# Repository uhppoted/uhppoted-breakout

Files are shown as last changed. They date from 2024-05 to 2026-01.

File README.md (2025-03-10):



# uhppoted-breakout

Breakout board for the UHPPOTE TCP/IP Wiegand 26 access controllers. 

The breakout board substitutes the removable CPU board with a hackable board that:
- Exposes the interface connector pins as a pair of standard 2.54mm (0.1") headers
- Serialises card swipes and I/O events out to an SPI interface
- Has mounting holes for an external CPU to do the heavy lifting (e.g. _RaspberryPi_ _Zero2W_)
- Includes an onboard RTC

## Raison d'être

Mostly curiosity? But .. it also opens up the possibility of:
- IPv6
- TLS
- UDP multicast
- onboard WiFi
- interfacing with off brand readers and keypads
- custom access control requirements

## Roadmap

### Rev.0

**IN DEVELOPMENT**

Initial proof of concept, designed to be relatively easy to hand solder and debug:
- All the components are on the front (top) of the PCB
- It uses the ever-so-cute _WaveShare_ _RP2040-Tiny_ module
- Through-hole components where convenient

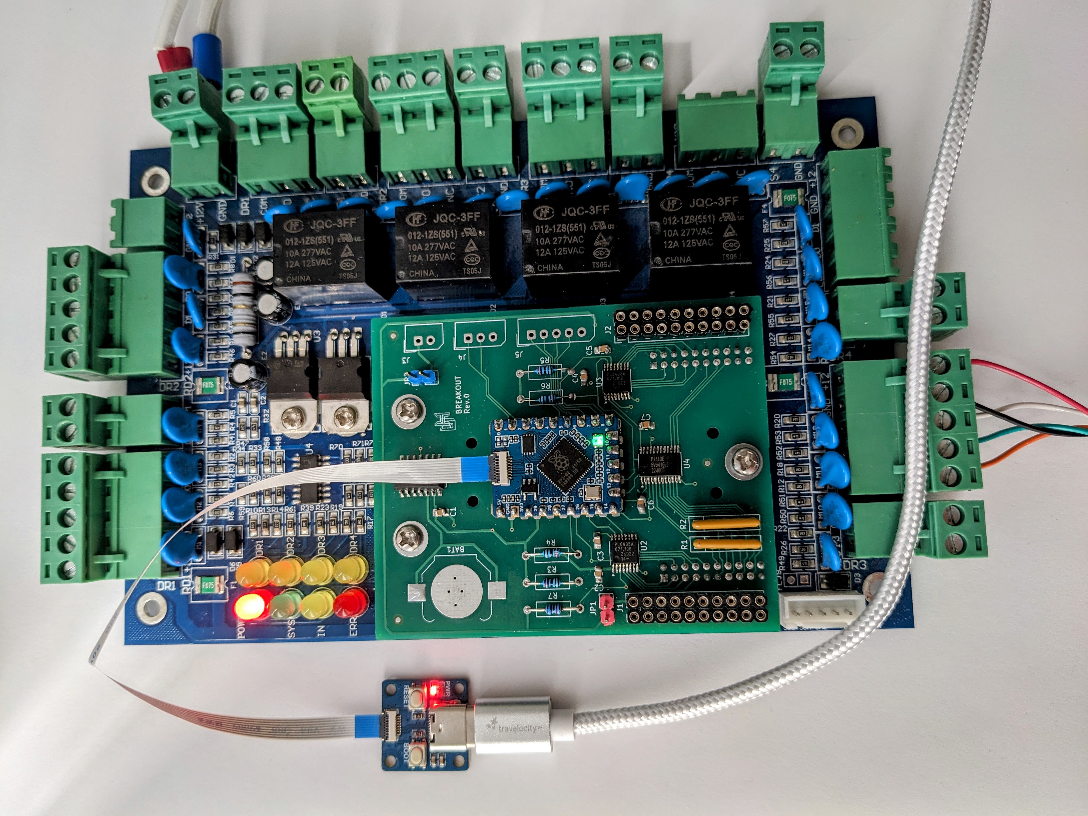
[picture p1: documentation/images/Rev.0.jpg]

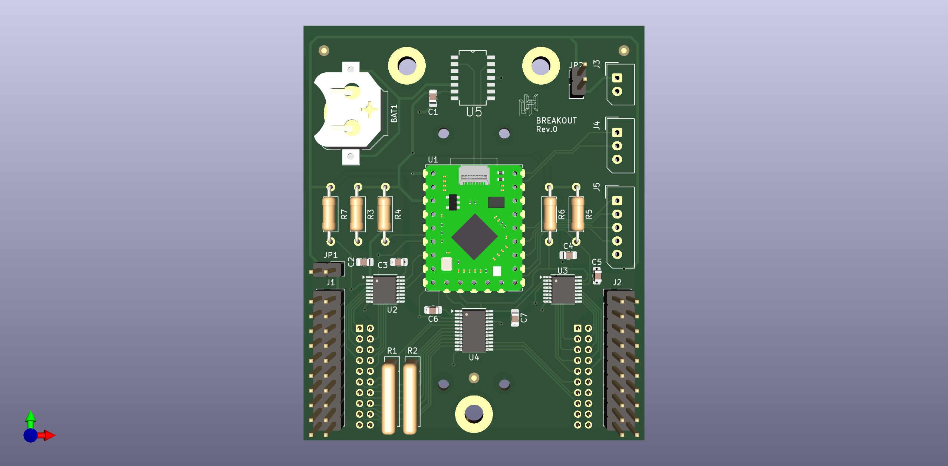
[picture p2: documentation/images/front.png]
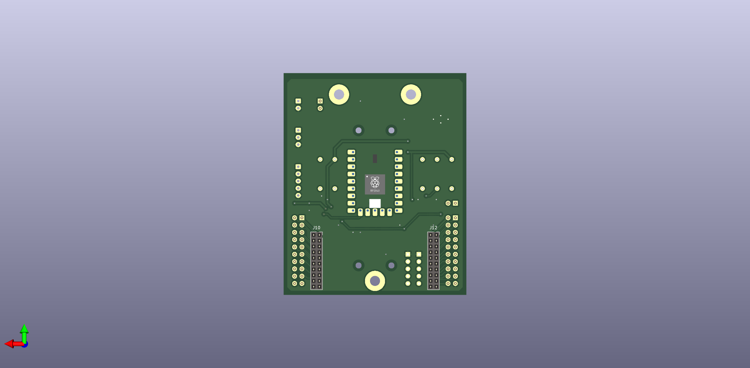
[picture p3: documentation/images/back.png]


#### Errata
1. Requires Schottky barrier diode and resistor on RX8900SA backup battery.
2. Add-on mounting holes are for RaspberryPi Pico.

## Notes

### Footprints
1. The silkscreen footprint for J10 and J12 on the CPU board of the controller is either mirrored or
   using the footprint for a pin header (presumably because the pin and socket headers were swapped for
   easier assembly and the silkscreen was never updated).

2. The silkscreen footprint for J10 and J11 on the base board of the controller is either mirrored or
   using the footprint for a pin socket (presumably because the pin and socket headers were swapped for
   easier assembly and the silkscreen was never updated).

3. The breakout board uses the correct footprints for the J10 and J12 socket headers that connect the
   board to the base board.

## License

Hardware is licensed under the CERN-OHL-S-2.0-S license, software is licensed under the MIT license.

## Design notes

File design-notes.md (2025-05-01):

# DESIGN NOTES

## UT0311L04

### Power Consumption

| Configuration | Measured | Power  |
|---|---|---|
| Base + CPU | 155mA  @ 12.21V | 1.9W |
| Base | 16.5mA @ 12.23V | 0.2W |
| Breakout Rev 0.0 | 25.4mA @ 5.10V  | 0.13W  |

### Startup

| RELAY | N/O | N/C | LED |
|---|---|---|-----|
| 1 | OPEN | CLOSED | +5V |
| 2 | OPEN | CLOSED | +5V |
| 3 | OPEN | CLOSED | +5V |
| 4 | OPEN | CLOSED | +5V |

### Relays
1. +5V/(1k || 10.470k) = 4.5mA
2. ULN2003A = 5V * 10k(10k + 470) = 4.77V

### Reader LEDs
1. +5V/470 = 10.6mA
2. Assumed to be high impendance signal (not driving LED directly)

### SYS, ERR and IN LEDs
1. (+5V - D5 - D6)/1k = (+5V - 0.6 - 0.6)/1k = 3.8mA

### References
1. https://www.cnx-software.com/2021/12/09/raspberry-pi-zero-2-w-power-consumption
2. https://raspi.tv/2017/how-much-power-does-pi-zero-w-use

## PCAL6408APW

### Input Schmmitt trigger
- Vᴅᴅ   = 5V
- Vʟᴏᴡ  = 0.3Vᴅᴅ (1.5V)
- Vʜɪɢʜ = 0.7Vᴅᴅ (3.5V)
- Vʜ    = 3.5V - 1.5V = 2V

## SSMP
1. Does not handle bignums.

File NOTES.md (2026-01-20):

# NOTES

1.  https://www.digikey.ca/en/articles/use-tight-pitch-board-to-board-connectors
2.  https://github.com/vlang/vinix
3.  BSS1338 or 2N7002 https://hackaday.com/2023/05/02/fet-fun-endeavors-together
4.  https://hackaday.com/2016/12/05/taking-it-to-another-level-making-3-3v-and-5v-logic-communicate-with-level-shifters/
5.  https://www.cnx-software.com/2023/10/09/waveshare-rp2040-pizero-raspberry-pi-rp2040-board-raspberry-pi-zero-form-factor/
6.  https://hackaday.com/2024/03/18/rnode-a-portable-unrestricted-digital-radio
7.  https://www.diodes.com/design/support/technical-articles/simplify-your-embedded-designs-using-ic-io-expanders
8.  https://www.diodes.com/assets/Datasheets/PI4IOE5V6416.pdf
9.  https://www.diodes.com/assets/Datasheets/PI4IOE5V6524.pdf
10. SMD adapters
    - https://www.icbreakout.com/products/qfn-24-breakout-board-4x4-mm-0-5-mm
    - https://www.artekit.eu/products/breakout-boards/bbadapters/tssop-to-dip/da-tssop24-p65
    - https://www.mikroe.com/tssop-ssop-24-to-dip24-300mil-adapter
    - https://www.aliexpress.com/item/1195743182.htm
11. https://electronics.stackexchange.com/questions/1849/is-there-a-correct-resistance-value-for-i2c-pull-up-resistors
12. https://learn.sparkfun.com/tutorials/micromod-rp2040-processor-board-hookup-guide/all#introduction
13. https://pmdway.com/products/soic24-tssop24-to-dip-adaptor-pcbs-10-pack
14. https://www.aliexpress.com/item/2039729656.html
15. https://www.mouser.ca/ProductDetail/TE-Connectivity/2-2316108-0
16. https://www.te.com/usa-en/product-2-2316108-0.html
17. https://electronics.stackexchange.com/questions/327455/multi-byte-i2c-read-not-working-while-equivalent-arduino-one-does

18. https://nats.io
19. https://store.particle.io/collections/all-products/products/photon-2
20. https://youtu.be/RrUyS-gixWk?si=QhU_jPk8qZ5NfyuA
21. Gateway discovery
    - https://github.com/jackpal/gateway
    - https://gist.github.com/jftuga/18409ced62f9a59ecbc047800ab8e810
    - https://forum.golangbridge.org/t/get-set-network-interface-in-pure-go-code/9075/3
22. [Memory usage](https://forums.raspberrypi.com/viewtopic.php?t=347638)
23. https://electronics.stackexchange.com/questions/742062/robust-communication-between-%c2%b5p-board-and-i-o-expander-over-3-5-meters
24. [OTA/UART](https://pfister.dev/blog/2025/rp2350-uart-bl.html)
25. (?) prevent power from I/O

## WaveShare RP2040-Tiny
1. https://tinygo.org/docs/reference/microcontrollers/machine/waveshare-rp2040-zero
```
On some boards, the XOSC can take longer than usual to stabilize. On such boards, this is needed to avoid a hard fault on boot/reset. Refer to PICO_XOSC_STARTUP_DELAY_MULTIPLIER in the Pico SDK for additional details.
``` 

## malloc/free
- https://forums.raspberrypi.com/viewtopic.php?t=361131
- https://github.com/raspberrypi/pico-sdk/issues/426
- https://forums.raspberrypi.com/viewtopic.php?t=336993
- https://interrupt.memfault.com/blog/boostrapping-libc-with-newlib

- https://community.st.com/t5/stm32cubeide-mcus/newlib-malloc-locking-mechanism-to-be-thread-safe/td-p/240082
- https://www.nadler.com/embedded/newlibAndFreeRTOS.html
- https://stackoverflow.com/questions/39088598/malloc-in-newlib-does-it-waste-memory-after-one-big-failure-allocation
- https://esp32.com/viewtopic.php?t=8419
- https://forums.freertos.org/t/malloc-free-thread-interrupt-safe/3452
- https://stackoverflow.com/questions/43222519/malloc-alternative-for-interrupt-safety
- https://stackoverflow.com/questions/855763/is-malloc-thread-safe
- https://github.com/eblot/newlib/blob/master/newlib/libc/sys/linux/malloc.c
- https://github.com/ARM-software/CMSIS_5/issues/177
- https://www.reddit.com/r/embedded/comments/9uvogb/freertos_malloc_and_c_standard_library/

> No, it is not thread-safe. There may actually be a malloc_lock() and malloc_unlock() function available in your
> C library. I know that these exist for the Newlib library. I had to use this to implement a mutex for my
> processor, which is multi-threaded in hardware.

## RX8900SA
1. https://github.com/citriena/RX8900RTC/blob/master/src/RX8900RTC.cpp

## PCAL6416A
- https://community.nxp.com/t5/Other-NXP-Products/Unable-to-write-Port-1-in-PCAL6416A/m-p/1219480#M10322

## SPI
   - https://learn.sparkfun.com/tutorials/raspberry-pi-spi-and-i2c-tutorial/all#spi-on-pi
   - https://embetronicx.com/tutorials/linux/device-drivers/linux-kernel-spi-device-driver-tutorial
   - https://github.com/cpb-/spi-tools
   - https://github.com/joan2937/picod/blob/master/DAEMON/picod.c
   - https://raspberrypi.stackexchange.com/questions/138460/software-spi-interrupt
   - https://raspberrypi.stackexchange.com/questions/140153/pi-pico-spi-interrupt-only-fires-once
   - https://www.circuitstate.com/tutorials/making-two-raspberry-pi-pico-boards-communicate-through-spi-using-c-cpp-sdk/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
   - https://www.digikey.ca/en/maker/projects/raspberry-pi-pico-rp2040-spi-example-with-micropython-and-cc/9706ea0cf3784ee98e35ff49188ee045
   - https://raspberrypi.stackexchange.com/questions/132758/what-is-the-pico-max-spi-frequency
   - https://github.com/espressif/esp-idf/issues/4810
   - https://forums.raspberrypi.com/viewtopic.php?t=30052
   - https://forums.raspberrypi.com/viewtopic.php?t=324252
   - https://github.com/raspberrypi/pico-examples/tree/master/spi/spi_dma
   - https://forums.raspberrypi.com/viewtopic.php?t=338108
   - https://people.ece.cornell.edu/land/courses/ece4760/RP2040/C_SDK_DMA_machine/DMA_machine_rp2040.html
   - https://blog.adafruit.com/2023/01/24/using-direct-memory-access-dma-on-the-rp2040-chip-raspberrypi-rp2040-dma
   - https://stackoverflow.com/questions/66388451/how-to-use-raspberry-pi-pico-with-dac-with-spi-to-generate-sine-wave-of-1-khz-wi

## Debouncing
- https://www.eejournal.com/article/ultimate-guide-to-switch-debounce-part-1

## USB
   - https://forums.raspberrypi.com/viewtopic.php?t=302960
   - https://stackoverflow.com/questions/29354228/is-stdout-required-to-be-a-text-stream

## CRCs
- https://stackoverflow.com/questions/10564491/function-to-calculate-a-crc16-checksum

## ASN.1
- https://learn.microsoft.com/en-gb/windows/win32/seccertenroll/about-integer?redirectedfrom=MSDN
- https://www.ranecommercial.com/legacy/note161.html
- https://www.oss.com/asn1/resources/asn1-made-simple/asn1-quick-reference/basic-encoding-rules.html

## SSMP
- https://stackoverflow.com/questions/29354228/is-stdout-required-to-be-a-text-stream
- https://forums.raspberrypi.com/viewtopic.php?t=302960
- https://www.baeldung.com/cs/bisync
- [PPP](https://datatracker.ietf.org/doc/html/rfc1661)
- https://learn.microsoft.com/en-us/windows/win32/snmp/snmp-error-codes

### Serial I/O
- https://stackoverflow.com/questions/51609813/serial-communication-in-c-for-raspberry-pi
- https://stackoverflow.com/questions/6947413/how-to-open-read-and-write-from-serial-port-in-c
- https://tldp.org/HOWTO/Serial-Programming-HOWTO/x56.html
- https://stackoverflow.com/questions/10564491/function-to-calculate-a-crc16-checksum
- https://stackoverflow.com/questions/76367736/uart-tx-produce-endless-interrupts-how-to-acknowlage-the-interrupt
- socat: https://tinkering.xyz/async-serial/

## Crypto
- https://www.jstage.jst.go.jp/article/transinf/E99.D/8/E99.D_2015INP0013/_article
- https://github.com/ubirch/ubirch-mbed-nacl-cm0
- https://www.semanticscholar.org/paper/True-random-number-generation-on-an-Atmel-AVR-Hlav%C3%A1c-L%C3%B3rencz/3948b47a9fb7a6b3632a1b631035bec3972932bc

## TLS
- https://eli.thegreenplace.net/2021/go-socket-servers-with-tls
- https://www.electricmonk.nl/log/2018/06/02/ssl-tls-client-certificate-verification-with-python-v3-4-sslcontext/

## Flash ID
1. https://forums.raspberrypi.com/viewtopic.php?t=331351
2. https://forums.raspberrypi.com/viewtopic.php?t=316853
3. https://forums.raspberrypi.com/viewtopic.php?t=316853

## RTC
`rtc_set_datetime` always increments the second i.e. `rtc_set_datetime` followed by `rtc_get_datetime` will always
return a date/time that is a second after the _set_ datetime.

1. https://forums.raspberrypi.com/viewtopic.php?t=325598
2. https://forums.raspberrypi.com/viewtopic.php?t=377876
3. https://forums.raspberrypi.com/viewtopic.php?t=348730
4. https://www.raspberrypi.com/documentation/pico-sdk/high_level.html#group_pico_aon_timer

error:+499.991 error:+499.976 error:+499.954 error:+499.979 
error:-250.044 error:-287.511 error:-325.027 error:-296.922 
error:-62.516  error:+15.320  error:+98.755  error:+35.670  
error:-62.503  error:-110.063 error:-178.581 error:-125.191 
error:-39.064  error:-21.004  error:+28.248  error:-11.869  
error:-27.368  error:-40.332  error:-80.826  error:-47.282  
error:-18.543  error:-14.670  error:+10.491  error:-11.185  
error:-12.676  error:-15.765  error:-34.946  error:-18.197  
error:-8.672   error:-7.727   error:+4.393   error:-6.461   
error:-5.938   error:-6.506   error:-14.884  error:-7.273   
error:-4.044   error:-3.717   error:+1.896   error:-3.282   
error:-2.741   error:-2.775   error:-6.344   error:-2.972   
error:-1.889   error:-1.728   error:+0.839   error:-1.549   
error:-1.272   error:-1.202   error:-2.695   error:-1.273   
error:-0.875   error:-0.766   error:+0.377   error:-0.727   
error:-0.619   error:-0.669   error:-1.148   error:-0.545   
error:-0.421   error:-0.261   error:+0.167   error:-0.341   
error:-0.255   error:-0.250   error:-0.480   error:-0.221   
error:-0.210   error:-0.109   error:+0.069   error:-0.166   
error:-0.135   error:-0.101   error:-0.222   error:-0.090   
error:-0.065   error:-0.060   error:+0.035   error:-0.051   
error:-0.077   error:-0.044   error:-0.121   error:-0.038   

# printf
1. https://github.com/picolibc/picolibc/blob/main/doc/printf.md
2. https://embeddedartistry.com/blog/2019/11/06/an-embedded-friendly-printf-implementation
3. https://github.com/LukeShu/pico-fmt
4. https://popovicu.com/posts/bare-metal-printf
5. https://stackoverflow.com/questions/9225567/how-to-portably-print-a-int64-t-type-in-c/9225648#9225648

## I2C
1. pullups
   - https://electronics.stackexchange.com/questions/1849/is-there-a-correct-resistance-value-for-i2c-pull-up-resistors
   - https://www.ti.com/lit/an/slva689/slva689.pdf
   - https://www.edn.com/design-calculations-for-robust-i2c-communications/

## Miscellaneous
1. DC-DC converter modules:
   - https://www.sparkfun.com/products/18375
   - https://www.adafruit.com/product/1065
   - https://www.adafruit.com/product/4739
   - https://www.adafruit.com/product/1385

   ## Relays
   1. https://uk.rs-online.com/web/p/signal-relays/6839851

2. WiFi
   - https://github.com/piersfinlayson/airfrog

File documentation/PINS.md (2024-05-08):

# PINs

## Base board

| J11                           || J10                            |
|----|---------|----|-----------||----|----------|----|-----------|
| 20 | DO1     | 1  | +5VDC     || 20 | SCL      | 1  | SDA       |
| 19 | DI1     | 2  |  DI4      || 19 | PB4      | 2  | S1        |
| 18 | DO2     | 3  |  DO4      || 18 | PB3      | 3  | S2        |
| 17 | DI2     | 4  |  DI3      || 17 | PB2      | 4  | S3        |
| 16 | NC      | 5  |  DO3      || 16 | PB1      | 5  | S4        |
| 15 | DR1 LED | 6  |  RELAY1   || 15 | SYS LED  | 6  | NC        |
| 14 | DR2 LED | 7  |  RELAY2   || 14 | IN  LED  | 7  | NC        |
| 13 | DR3 LED | 8  |  RELAY3   || 13 | ERR LED  | 8  | NC        |
| 12 | DR4 LED | 9  |  RELAY4   || 12 | VREF     | 9  | GND       |
| 11 | GND     | 10 |  VREF     || 11 | NC       | 10 | NC        |
|----|---------|----|-----------||----|----------|----|-----------|

## CPU board

| J10                           || J12                           |
|----|----------|----|----------||----|-----------|----|---------|
| 1  | SDA      | 20 | SCL      || 1  | +5VDC     | 20 | DO1     |
| 2  | S1       | 19 | PB4      || 2  |  DI4      | 19 | DI1     |
| 3  | S2       | 18 | PB3      || 3  |  DO4      | 18 | DO2     |
| 4  | S3       | 17 | PB2      || 4  |  DI3      | 17 | DI2     |
| 5  | S4       | 16 | PB1      || 5  |  DO3      | 16 | NC      |
| 6  | NC       | 15 | SYS LED  || 6  |  RELAY1   | 15 | DR1 LED |
| 7  | NC       | 14 | IN  LED  || 7  |  RELAY2   | 14 | DR2 LED |
| 8  | NC       | 13 | ERR LED  || 8  |  RELAY3   | 13 | DR3 LED |
| 9  | GND      | 12 | VREF     || 9  |  RELAY4   | 12 | DR4 LED |
| 10 | NC       | 11 | NC       || 10 |  VREF     | 11 | GND     |
|----|----------|----|----------||----|-----------|----|---------|

## Miscellaneous

1.  3.3VDC supply seems to be on CPU board
    - AMS1117
2.  Connectors are 2x10P 2mm pitch
3.  FLJ9 is just GND and +5VDC
4.  Mounting holes are 3.5mm dia.
5.  CPU board
    - width: 63.25mm (63.5mm = 2.5")
    - height: 75mm (76.2mm = 3")
6.  J10.1 to J12.1 is 41.5mm (40.64mm = 16*2.54)
7.  Single mounting hole:
    - centre to J10.1: 21.75mm
    - centre to J12.1 20.0mmmm
    - because 2mm header column spacing
8.  Double mounting holes
    - ~65mm    from single mounting hole
    - ~64.25mm from single mounting hole
    - (64.1 + 64.8)/2 = 64.45
    - 68.0 - 3.5 = 64.5
    - 64.77 = 51*1.27
    - distance between = 25mm
    - ** offset 64.5mm
    - ** seperation 25mm
9.  Silkscreen has used pin header footprint for sockets J10 and J12 on CPU board
10. Silkscreen has used pin socket footprint for header J10 and J11 on base board

### Remeasured

1. J11 P1 to J10 P1: 40.9mm (but 2.3mm measured is 2mm pin-to-pin)
2. J11 P1 to mounting hole centre: 21.5 (~20.32 ??)
3. Mounting hole centre in line with pin 9 of J10/J11
4. Mounting hole center to J11 pin 1 is 50.0mm
5. Mounting hole center to J10 pin 1 is 59.0mm

## Wiegand Reader I/O

1. 470 + 10k ohms series resistance
2. ??  capacitor
3. LPF presumably
4. VREF is the nominal +5VDC supplied to the reader digital pins
5. VREF is common on the 'other side' of the resistors

## Relays

1. Nominally 12V relay
2. Active high:
   - locked: 0VDC
   - unlocked: 2.6VDC
3. RELAY 1 - R42 - NXP p40
4. RELAY 2 - R43 - NXP p50
5. RELAY 3 - R44 - NXP p44
6. RELAY 4 - R45 - NXP p45

## LEDs

1. On board DOOR LEDs are probably on relay signal
2. READER LEDs are 5V pulled to GND
3. SYS, IN and ERR LED are 3.3V pulled to GND

## SIO

1. SCL is 3.3V, pullup
2. SDA is 3.3V, pullup

## FLJ9

## Connectors

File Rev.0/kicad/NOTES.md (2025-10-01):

# NOTES

## Rev.1

**SERIOUSLY CONSIDER REPLACING THE I2C OUTPUTS WITH A LEVEL CONVERTER**

0.  I/O expanders RESET pin should be tied low *ALSO* currently connected to 5V ??????
1.  Renumber Tiny PINS to match WaveShare wiki (and keep copy of pinout in documentation folder)
2.  Schottkey diodes and resistor for RX8900SA VBAT
    - https://www.diodes.com/assets/Datasheets/SDM03U40.pdf
2.  Decoupling capacitor on RX8900SA VBAT
3.  (?) Tie FOE pin low through zero ohm resistor (with pullup to VDD)
4.  **Remove SPI and route both UART0 and UART1**
5.  Pullups on INT0 and INT1
6.  Relays and reader LEDs should be open collector and tied to +5V (fail open and red LED_s
7.  (?) RESET should be tied low to hold U2 et al in reset until U5 is ready
8.  R1 and R2 - maybe increase resistance (2.5K? 10K?)
9.  1206 or 0804 or 0603 resistors and capacitors ?
10. Connect NC pins on J10 to J2
11. Connect NC    pins on J12 to J12
12. Tie RX8900SA NC pins to GND
13. Fix PiZero2W mounting holes
    - https://www.tomshardware.com/news/waveshares-rp2040-pi-zero-morphs-raspberry-pi-pico-into-zero
14. PiZero2W header (surface mount)
15. Debug/state LEDs
16. BOM: 1.6mm x dia. 6.5mm washer for standoffs
17. BOM: M3x5 screws
18. BOM: Machine pin header and socket
19. Use smaller (2.0mm?) board-to-board connectors (J2,J3,J4)
20. Allow for external 3.3V
21. Replace Diodes Inc PI4IOE5V6416 with NXP equivalent
22. J10/J12 soldering jig
23. Test baseboard
24. Fix logo
25. Use machine pin socket on dev. board.
26. Relay startup click
27. SYS LED not driven
28. Reset/reboot button
29. Slot for USB ribbon
30. PiZero2W mounting holes are M2.5
31. Route GND and +5V to PiZero2W header (jumper on +5V)
32. Route UART0 and UART1 to PiZero2W header (with solder bridges/zero ohm resistors)
33. DO and DI are actual D0 and D1, etc
34. Protection resistors (560 ohms?) on UART pins
35. Pullups on UART pins
    - https://electronics.stackexchange.com/questions/270834/pull-up-resistors-on-uart
35. Add RTS and CTS to UART header
36. Connect RX8900SA 1s output to GPIO
37. Connect RX8900SA ALARM output to reset (jumper)
38. Seriously consider an external hardware watchdog
39. Rev.1-Pico (with pico footprint on back)
40. 3v3 test point
41. 5VDC test point
42. GND test point
43. External I2C (SCL/SDA)
    - fire alarm
    - tamper detect
    - (?) maybe route additional connector to spare GPIO mux for
        - fire alarm
        - tamper detect
44. External watchdog (?)
    - Jumper to disable
    - https://www.ganssle.com/watchdogs.htm
45. 470 ohm protective resistors on inputs
46. PCAL6416A: tie unused outputs to ground via 10k

(?) RS-485 for serial I/O (multidrop)
(?) Maybe put GND on pin 1 of UART/SPI header
(?) https://www.olimex.com/Products/Components/IC/SY6280
    - https://hackaday.com/2024/07/03/usb-and-the-myth-of-500-milliamps/

(?) Mounting holes for external 12V power supply
(?) Slightly larger pads for soldering
(?) https://www.chipquik.com/store/product_info.php?products_id=1900050
(?) Jumper VBAT to VDD for no battery option
(?) https://www.flux.ai/p

### RX8900SA
1. RX8025

- https://electronics.stackexchange.com/questions/348095/coin-cell-battery-recharging-circuit-for-rtc-backup-power
- https://electronics.stackexchange.com/questions/410853/minimalistic-rtc-backup-battery-charging-or-a-super-capacitor
- https://electronics.stackexchange.com/questions/60690/will-checking-the-backup-voltage-on-an-rtc-drain-its-backup-battery
- https://electronics.stackexchange.com/questions/564726/how-can-i-measure-cr2032-rtc-battery-voltage-in-a-microprocessor-system
- https://www5.epsondevice.com/en/information/support/pdf/RTC-EVA2-Easy-instruction-ENG-Ver00.pdf
- https://www.mouser.ca/c/?marcom=126457092

## JLPCB
1. Solder stencil does not require BAT1 and U1 pads (large enough to hand solder).
2. Set custom stencil size when ordering.

## Misc.
1. Don't use flux paste on through holes (hard to clean, especially under jumpers and headers)

## Wiegand DI1/DO1
DEBUG  reader     ... f7 11110111  0 DO1
DEBUG  reader     ... f7 11110111  0 DO1
DEBUG  reader     ... fb 11111011  1 DI1
DEBUG  reader     ... fb 11111011  1 DI1
DEBUG  reader     ... f7 11110111  0 DO1
DEBUG  reader     ... f7 11110111  0 DO1
DEBUG  reader     ... fb 11111011  1 DI1
DEBUG  reader     ... f7 11110111  0 DO1
DEBUG  reader     ... f7 11110111  0 DO1
DEBUG  reader     ... fb 11111011  1 DI1
DEBUG  reader     ... fb 11111011  1 DI1
DEBUG  reader     ... fb 11111011  1 DI1
DEBUG  reader     ... f7 11110111  0 DO1
DEBUG  reader     ... f7 11110111  0 DO1
DEBUG  reader     ... fb 11111011  1 DI1
DEBUG  reader     ... f7 11110111  0 DO1
DEBUG  reader     ... f7 11110111  0 DO1
DEBUG  reader     ... f7 11110111  0 DO1
DEBUG  reader     ... f7 11110111  0 DO1
DEBUG  reader     ... f7 11110111  0 DO1
DEBUG  reader     ... fb 11111011  1 DI1
DEBUG  reader     ... fb 11111011  1 DI1
DEBUG  reader     ... fb 11111011  1 DI1
DEBUG  reader     ... fb 11111011  1 DI1
DEBUG  reader     ... fb 11111011  1 DI1
DEBUG  reader     ... fb 11111011  1 DI1

10058399
0C9C83F
0 0110 0100 1110 0100 0001 1111 1

0 0110 0100 1110 0100 0001 1111 1

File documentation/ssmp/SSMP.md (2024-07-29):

# Simple Serial Management Protocol (SSMP)

## ENQ

Establishes connection, switching serial port from CLI to SSMP if necessary.

```
REQUEST:   SYN SYN ENQ
RESPONSE:  SYN SYN ACK
```

## GetRequest

Requests a PDU by MIB OID.

```
REQUEST:   SYN SYN SOH ... STX GET <OID><ETX>
RESPONSE:  SYN SYN ACK ... STX <value> <ETX>
```

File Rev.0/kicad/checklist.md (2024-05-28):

# Checklist

## J3
- [ ] short circuit
- [ ] resistance to GND

## J4
- [ ] short circuit
- [ ] resistance to GND

## J5
- [ ] short circuit
- [ ] resistance to GND

## J10

- [x] short circuits
- [x] GND
- [x] J2
      - [x] pin 1 (SCL)
      - [x] pin 2 (SDA)
      - [x] pin 3 (PB4)
      - [x] pin 4 (S1)
      - [x] pin 5 (PB3)
      - [x] pin 6 (S2)
      - [x] pin 7 (PB2)
      - [x] pin 8 (S3)
      - [x] pin 9 (PB1)
      - [x] pin 10 (S4)
      - [x] pin 11 (SYS)
      - [x] ~~pin 12 (NC)~~
      - [x] pin 13 (IN)
      - [x] ~~pin 14 (NC)~~
      - [x] pin 15 (ERR)
      - [x] ~~pin 16 (NC)~~
      - [x] pin 17 (VREF)
      - [x] pin 18 (GND)
      - [x] ~~pin 19 (NC)~~
      - [x] ~~pin 20 (NC)~~

## J12

- [x] short circuits
- [x] GND
- [x] +5V
- [x] J1
      - [x] pin 1 (DO1)
      - [x] pin 2 (PWR)
      - [x] pin 3 (DI1)
      - [x] pin 4 (DI4)
      - [x] pin 5 (DO2)
      - [x] pin 6 (DO4)
      - [x] pin 7 (DI2)
      - [x] pin 8 (DI3)
      - [x] ~~pin 9 (NC)~~
      - [x] pin 10 (DO3)
      - [x] pin 11 (DR1)
      - [x] pin 12 (RELAY1)
      - [x] pin 13 (DR2)
      - [x] pin 14 (RELAY2)
      - [x] pin 15 (DR3)
      - [x] pin 16 (RELAY3)
      - [x] pin 17 (DR4)
      - [x] pin 18 (RELAY4)
      - [x] pin 19 (GND)
      - [x] pin 20 (VREF)

## J1/JP1

- [x] +5V

## J3/JP2 

- [x] GND
- [x] +5V

## U1

- [x] short circuits
- [x] GND
- [x] +5V
- [x] 3.3V

## U2

- [x] short circuits
- [x] GND
- [x] +5V
- [x] +3.3V

## U3

- [x] short circuits
- [x] GND
- [x] +5V
- [x] +3.3V

## U5

- [x] short circuits
- [x] GND
- [x] +3.3V
- [x] VBAT
- [x] SCL
- [x] SDA

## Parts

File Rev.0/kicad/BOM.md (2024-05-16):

### BOM: uhppoted-breakout Rev.0

| Item | Qty | Reference | Value | Part | Ordering |
|---|-----|---|---|---|---|
| 1 | 1 | BAT1 | - | Keystone 3000 1x12mm battery holder | [534-3000](https://www.mouser.ca/ProductDetail/534-3000) |
| 2 | 2 | J1-2 | - | 2x10P 2.54mm vertical pin header | |
| 3 | 1 | J3 | - | 1x2P 2.54m vertical pin header | |
| 4 | 1 | J4 | - | 1x3P 2.54mm vertical pin header | |
| 5 | 1 | J5 | - | 1x5P 2.54mm vertical pin header | |
| 6 | 2 | J10,J12 | - | 2x10P 2mm vertical pin socket | |
| 7 | 2 | JP1-2 | - | 2.54mm jumper | |
| 8 | 7 | C1-7 | 0.1uF | 0805 tantulum decoupling capacitors | |
| 9 | 2 | R1-2 | 4x1k | 4x1k SIP5 resistor array | [652-4605X-AP1-102LF](https://www.mouser.ca/ProductDetail/652-4605X-AP1-102LF) |
| 10 | 4 | R3-6 | 2.2k | 1/8W TH 2.2k pullup resistors | |
| 11 | 1 | R7 | 10k | 1/8W TH 10k resistor | |
| 12 | 1 | U1 | RP2040 | Waveshare RP2020-Tiny | [WaveShare RP2040-Tiny](https://www.waveshare.com/wiki/RP2040-Tiny) |
| 13 | 2 | U2-3 | PCAL6408APW | 8 pin I2C I/O expander | [771-PCAL6408APWJ](https://www.mouser.ca/ProductDetail/771-PCAL6408APWJ) |
| 14 | 1 | U4 | PI4IOE5V6416LEX | 16 pin I2C I/O expander | [729-PI4IOE5V6416LEX](https://www.mouser.ca/ProductDetail/729-PI4IOE5V6416LEX) |
| 15 | 1 | U5 | RX8900SA | Epson-Seiko RTC | [732-RX8900SAUA0SN](https://www.mouser.ca/ProductDetail/732-RX8900SAUA0SN) |
| 16 | 3 | | | 1.6mm x 6.5mm dia. Nylon washers | |
| 17 | 2 | | | 8 pin socket header | |
| 18 | 1 | | | 5 pin socket header | |
| 19 | 1 | | CR1220 | 3.3V coin cell | [658-CR1220](https://www.mouser.ca/ProductDetail/658-CR1220) |

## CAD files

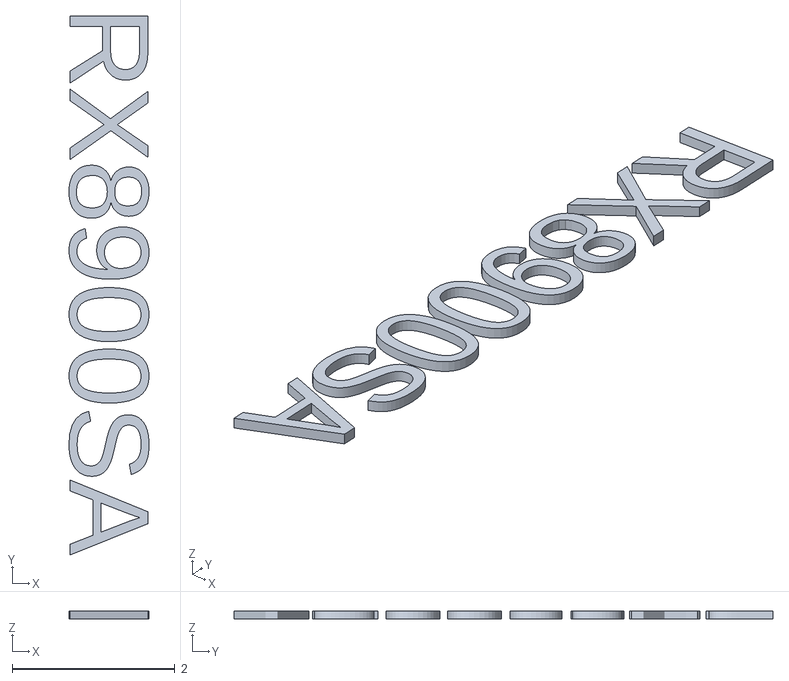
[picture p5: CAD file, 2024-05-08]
Rev.0/scripts/RX8900SA-label.stl
0.983 x 6.62 x 0.1

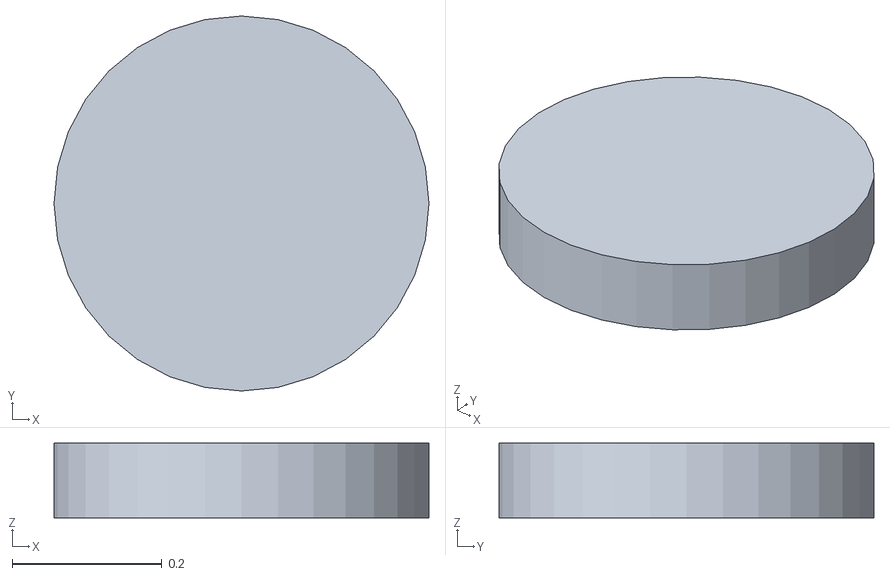
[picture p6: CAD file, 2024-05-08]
Rev.0/scripts/RX8900SA-dot.stl
0.5 x 0.5 x 0.1

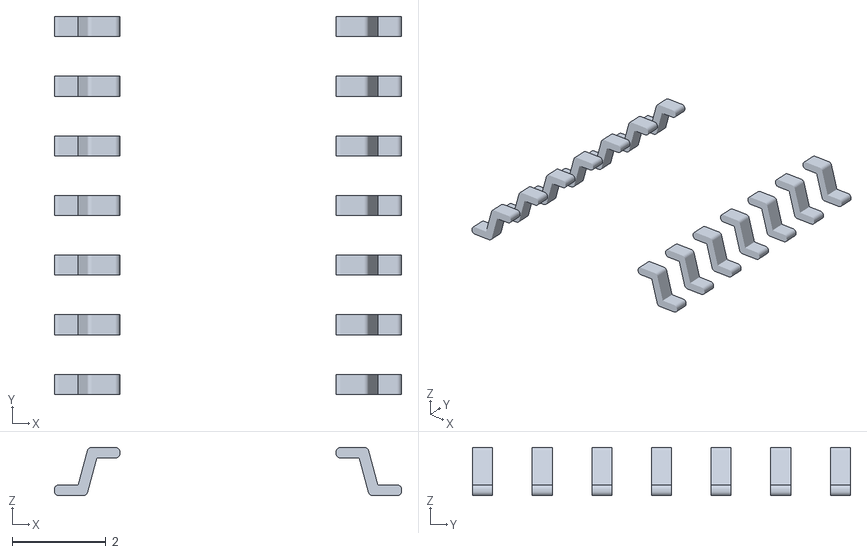
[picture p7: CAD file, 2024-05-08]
Rev.0/scripts/RX8900SA-pins.stl
7.40 x 8.05 x 1.03

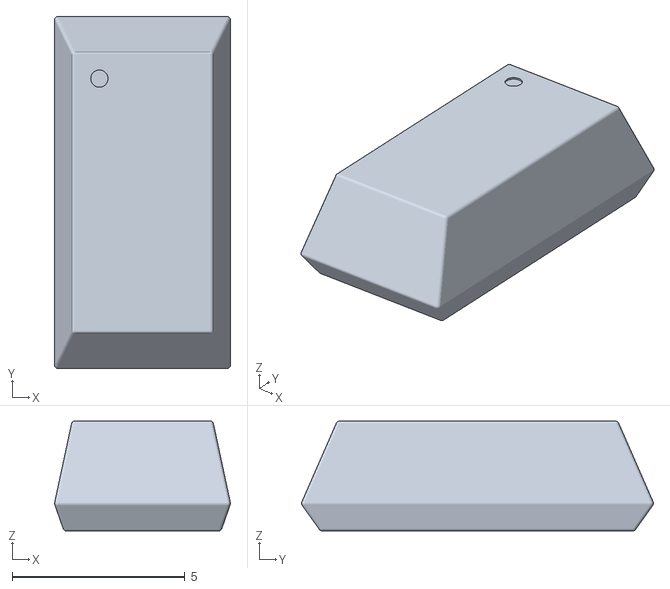
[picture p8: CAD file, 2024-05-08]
Rev.0/scripts/RX8900SA-body.stl
5.10 x 10.2 x 3.18

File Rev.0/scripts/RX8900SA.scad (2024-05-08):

$fn=32;

body_width=5;
body_length=10.1;
body_height=3.2;
body_pins=14;

pin_length=1.2;
pin_width=0.43;
pin_height=0.23;
pin_separation=1.27;
pin_loft=0.8;
pin_overlap=0.1;
pin_offset=(body_length - pin_separation*((body_pins/2)-1))/2;

module pin() {
    l = pin_length/2;
    w = pin_width;
    h = pin_height;
    dl = pin_overlap;
    dh = pin_loft;
    r = 0.1;

    color("silver")
      translate([0,w/2,0])
      rotate(90,[1,0,0])
      linear_extrude(w)
      minkowski(){
        polygon([
          [-dl,dh+r],
          [l-h/2-h/2,dh+r],
          [l-h/2+r,r],
          [2*l-r,r],
          [2*l-r,h-r],
          [l+h/2-r,h-r],
          [l+h/2-h/2-2*r,dh+h-r],
          [-dl,dh+h-r],
          [-dl,dh+r]
          ]);
        circle(r);
      };
}

module left_pin() {
    translate([-body_width/2,pin_offset,0])
      mirror([1,0,0]) 
        pin();
}

module right_pin() {
    translate([+body_width/2,pin_offset,0])
        pin();
}

module body() {
    color("#444444")
    translate([0,body_length/2,pin_loft+pin_height/2]) {
      minkowski() {
        union() {
          linear_extrude(height=body_height-pin_loft-pin_height/2,scale=0.8)
            square([body_width-0.1,body_length-0.1],center=true);

          mirror([0,0,1])
            linear_extrude(height=pin_loft-0.1,scale=0.9)
              square([body_width-0.1,body_length-0.1],center=true);
        };
        sphere(0.1);
      };
   };
}

module pins() {
    for (pin=[1:1:body_pins/2]) {
        offset = (pin-1)*pin_separation;

        translate([0,offset,0])
          left_pin();

        translate([0,offset,0])
         right_pin();
    }
}

module label() {
    color("white")
    translate([0,body_length/2,body_height]) 
      linear_extrude(0.1)
      scale(0.1)
      rotate(-90,[0,0,1])
      text("RX8900SA",halign="center");
}

module dot() {
    color("#666666")
    translate([-1.25,body_length-1.75,body_height+0.1]) 
    cylinder(0.1,0.25,0.25, center=true);
}

module RX8900SA() {
    translate([0,-body_length/2,0])
      difference() {
        union() {
          body();
          pins();
          label();
        };
        dot();
     };
}

RX8900SA();

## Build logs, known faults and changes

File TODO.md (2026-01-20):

# TODO

https://fgiesen.wordpress.com/2025/09/25/ceiling-division-and-mip-map-sizes/

- [ ] uhppote-cli::get-events

- [ ] card swipe
   - [ ] swipe + PIN
      - [x] reader LED
      - [x] use breakout keycode
      - [x] USB write errors
      - [ ] unexpected context cancelled
```
      2025-10-06 11:29:35 WARN   UT0311           swipe: anti-passback error  controller:405419896 door:1 card:10058400 (context canceled)
```
   - [ ] door open/closed seems to be inverted
   - (?) use pipes
   - (?) trap handlers

- [ ] passcode
    - [ ] set-door-passcodes
    - [ ] unlock door
    - [ ] events

- [ ] pushbutton
- [ ] open-door
      - [ ] event
      - [ ] ReasonOpenDeniedDoorNormallyClosed
      - [ ] ReasonOpenDeniedDoorInterLock

- [ ] _get-status_
   - [x] use cached values for door locks
   - [ ] use cached values for alarms 
   - [ ] poll
      - https://avi.im/blag/2025/setsum
      - pack state into byte array and send CRC every e.g. 500ms
      - ut0311 does the same and fetches packed state if CRCs don't match
   - [ ] clear watchdog error after logging it
   - (?) maybe use state tags like 'controller.405419896.xxxx....'

## RPCD
   - [ ] monitor interface
   - (?) Context.WithTimeout 
   - (?) https://go.dev/blog/synctest

## dbd
   - [ ] monitor interface
   - [ ] wrap DBC in struct that invalidates dbc on fatal error
   - [ ] commonalise _delete_

## breakout
- [ ] perfect hashing
      - https://blog.sesse.net/blog/tech/2025-10-23-21-23_modern_perfect_hashing.html

- [ ] // FIXME: rethink U4_blink_LED - not going to work correctly with different intervals
    - queue ?

- [] U4 erratic as hell
    - https://community.nxp.com/t5/Other-NXP-Products/Unable-to-write-Port-1-in-PCAL6416A/m-p/1154460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
    - https://github.com/BenjamimKrug/PCAL6416A
    - https://e2e.ti.com/support/interface-group/interface/f/interface-forum/1254274/tca6416a-output-pin-is-not-sending-the-desired-value
    - https://forums.raspberrypi.com/viewtopic.php?t=312340
    - https://forum.pycom.io/topic/6589/working-with-i2c-and-port-expander
    - https://raspberrypi.stackexchange.com/questions/139178/libgpiod-read-value-operation-not-permitted

- [ ] fairly frequent crash on settings::save
      - queue error maybe??
```
INFO   CLI        >>> queue    error
```

- [ ] USB
    - https://forums.raspberrypi.com/viewtopic.php?t=313998
    - https://github.com/piersfinlayson/tinyusb-vendor-example
    - https://github.com/piersfinlayson/picoboot

### misc

- [ ] PIO I2C
- [ ] make debugf, infof, etc interrupt safe
   - https://embeddedartistry.com/blog/2019/11/06/an-embedded-friendly-printf-implementation
   - https://github.com/LukeShu/pico-fmt
   - https://mcuoneclipse.com/2023/02/15/you_shall_not_use_printf-how-to-make-sure-no-printf-is-used/

- [ ] USB
    - [ ] picotool reset
        - https://forums.raspberrypi.com/viewtopic.php?t=366208
        - https://github.com/raspberrypi/picotool/issues/88
        - https://github.com/raspberrypi/picotool/pull/83
        - https://github.com/earlephilhower/arduino-pico/issues/2078
        - https://github.com/raspberrypi/picotool/blob/f6fe6b7c321a2def8950d2a440335dfba19e2eab/picoboot_connection/picoboot_connection.c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
        - https://github.com/raspberrypi/picotool/pull/177
        - https://github.com/illusiaDecafish/bootselBoot
        - https://github.com/raspberrypi/pico-sdk/blob/master/src/rp2_common/pico_stdio_usb/reset_interface.c
        - https://github.com/ithinuel/usbd-picotool-reset
        - https://github.com/dsi-modchip/firmware
        - https://github.com/tomas-pecserke/pico_tusb_reset_interface
        - https://github.com/hathach/tinyusb/discussions/664
        - https://github.com/piersfinlayson/tinyusb-vendor-example
        - https://github.com/Veyniac/Pico-Audio-Interface

- [ ] Rework print queue
      - (?) reservoir sampling (https://samwho.dev/reservoir-sampling)

- https://bogdanthegeek.github.io/blog/insights/jlink-rtt-for-the-masses/

### SSMP
   - [ ] TRAP
      - [ ] restructure
            - [x] traps update ut0311 state and state generates events
            - [ ] poll for current state
            - [x] get event info from state
            - [ ] replace callbacks with pipe
            - (?) map controller IDs to state
      - [x] inputs
         - generalize as input state change
      - [ ] power on/reset
         - generalize as system state change
      - [ ] swipe
      - [ ] alarm
      - [ ] //FIXME encode all var types

   - [x] save to flash
      - [x] door delay/mode
      - [x] interlock
      - [x] `DEBUG  DOORS  settings saved` on `set-time`
      - [ ] quite often goes off into the weeds ???

   - [ ] GET: multiple OIDs
   - [ ] MIB_find (returns const *MIBItem)
   - [ ] Use 'perfect' hash function
      - ref. https://www.gnu.org/software/gperf

## Zero2W
- [ ] serial logger
- [ ] custom image
      - https://github.com/raspberrypi/rpi-image-gen
- [ ] memory FS for Unix domain sockets
      - /run
      - /dev/shm
      - tmpfs

- [ ] set-time
   - https://stackoverflow.com/questions/48906483/how-to-set-systems-date-and-time-via-go-syscall
s
### UT0311
   - [x] open door on card swipe
   - [ ] open door on PB
   - [ ] rework with text tags

   - [ ] eventd
      - [ ] remove unnecessary OID stuff
      - [ ] move entities to shared lib

   - [ ] API
      - [x] get-controller
      - [x] set-address
      - [x] get-listener
      - [x] set-listener
      - [x] get-time
      - [x] set-time
      - [x] get-status
      - [x] get-door
      - [x] set-door
      - [x] set-door-passcodes
      - [x] get-cards
      - [x] get-card
      - [x] get-card-by-index
      - [x] put-card
      - [x] delete-card
      - [x] delete-all-cards
      - [x] open-door
      - [x] get-event-index
      - [x] set-event-index
      - [x] get-event
      - [x] record-special-events
      - [ ] get-time-profiles
      - [ ] set-time-profile
      - [ ] clear-time-profiles
      - [ ] add-task
      - [ ] clear-task-list
      - [ ] refresh-task-list
      - [ ] set-pc-control
      - [x] set-interlock
      - [ ] activate-keypads
      - [x] get-anti-passback
      - [x] set-anti-passback
      - [ ] restore-default-parameters

   - [ ] events
      - [ ] forced open

   - [ ] RPC
      - https://go.dev/blog/protobuf-opaque
      - [x] go-rpc
      - [x] unix domain sockets
      - [ ] go-rpc+json
      - [ ] TLS
      - [ ] TCP/IP
      - [ ] grpc

   - [ ] monitor
   - [ ] daemonize
   - [ ] idle poll
   - [ ] cache
   - [ ] tinygo
      - https://di-marco.net/blog/it/2020-06-06-raspberry_pi_3_4_and_0_w_serial_port_usage/

### MIB
   - [ ] RP2040 ID
      - https://www.raspberrypi.com/documentation/pico-sdk/hardware.html#rpip2aed586200427c10f67f
   - [ ] system errors
   - [ ] system error messages
   - [ ] use DATETIME, BOOLEAN, ENUMERATED etc

## PiZeroW
   - [ ] Reduce power consumption
      - https://hackaday.com/2024/10/03/pi-zero-power-optimization-leaves-no-stone-unturned
      - https://kittenlabs.de/blog/2024/09/01/extreme-pi-boot-optimization
   - [ ] NB: 24/7 operation - Cam said to ask him
   - (?) Use Nerves
   - https://hackaday.com/2025/03/26/build-customized-raspberry-pi-os-images-with-rpi-image-gen/

### OTA
   - https://blog.usedbytes.com/2021/12/pico-serial-bootloader/
   - https://www.youtube.com/watch?v=4-dle5L9REs
   - https://monocypher.org
   - https://groupgets.com/products/pureconnect

## R&D
- https://embeddedgo.github.io/2025/08/17/news.html
- https://mazzo.li/posts/fast-pipes.html
- Nerves
- Embassy (Rust)
- [Lean](https://kuruczgy.com/blog/2024/07/31/lean-esp32)
- [protothreads](https://dunkels.com/adam/pt/index.html)
- https://interrupt.memfault.com/blog/diving-into-jtag-part-6
- https://pwy.io/posts/marching-events/
- [ ] Pinout diagram
   - (?) [WireViz] https://github.com/formatc1702/WireViz
   - (?) https://github.com/cmfcmf/ic-pinout-diagram-generator
   - (?) https://pinouts.vercel.app/board/nodemcu-v2
   - (?) https://electronics.stackexchange.com/questions/73780/program-to-draw-pinouts-and-easily-visualize-pins-multiplexed-functions
   - (?) https://www.youtube.com/watch?v=ndVs1UvK6AE
   - (?) TeX
   - (?) https://www.sparkfun.com/news/1947
   - (?) https://www.flickr.com/photos/28521811@N04/
   - (?) https://github.com/stevenj/GenPinoutSVG
   - (?) https://yaqwsx.github.io/Pinion/
   - (?) https://github.com/splitbrain/pinoutleaf
- OCDSP
   - https://github.com/bytedreamer/Aporta
- Mongoose Wizard
   - https://mongoose.ws/wizard/#

- [Ocre/WASM](https://lfedge.org/projects/ocre)
- [atym/WASM](https://www.atym.io)

### Rust
- https://rtic.rs/1/book/en/preface.html
- https://github.com/embassy-rs/embassy

## Notes
1. https://github.com/yaqwsx/PcbDraw
2. https://yaqwsx.github.io/Pinion/
3. https://en.wikipedia.org/wiki/Simple_Service_Discovery_Protocol
4. https://en.wikipedia.org/wiki/Zero-configuration_networking
5. https://learn.sparkfun.com/tutorials/micromod-rp2040-processor-board-hookup-guide/all#introduction
6. https://www.proto-advantage.com/store/product_info.php?products_id=2200040
11. https://hackaday.com/2024/05/04/giving-your-kicad-pcb-repository-pretty-pictures/
12. External flash
   - https://mcuoneclipse.com/2022/12/04/add-extra-storage-to-the-raspberry-pi-pico-with-w25q128-and-littlefs
13. https://forums.raspberrypi.com/viewtopic.php?t=327189
14. https://hackaday.com/2024/04/17/human-interfacing-devices-hid-over-i2c
15, https://github.com/raspberrypi/pico-sdk/issues/224
16. https://github.com/raspberrypi/pico-sdk/issues/997

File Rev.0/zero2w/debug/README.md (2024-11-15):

# uhppoted-breakout

Python implementation of the _uhppoted-breakout_ emulator.

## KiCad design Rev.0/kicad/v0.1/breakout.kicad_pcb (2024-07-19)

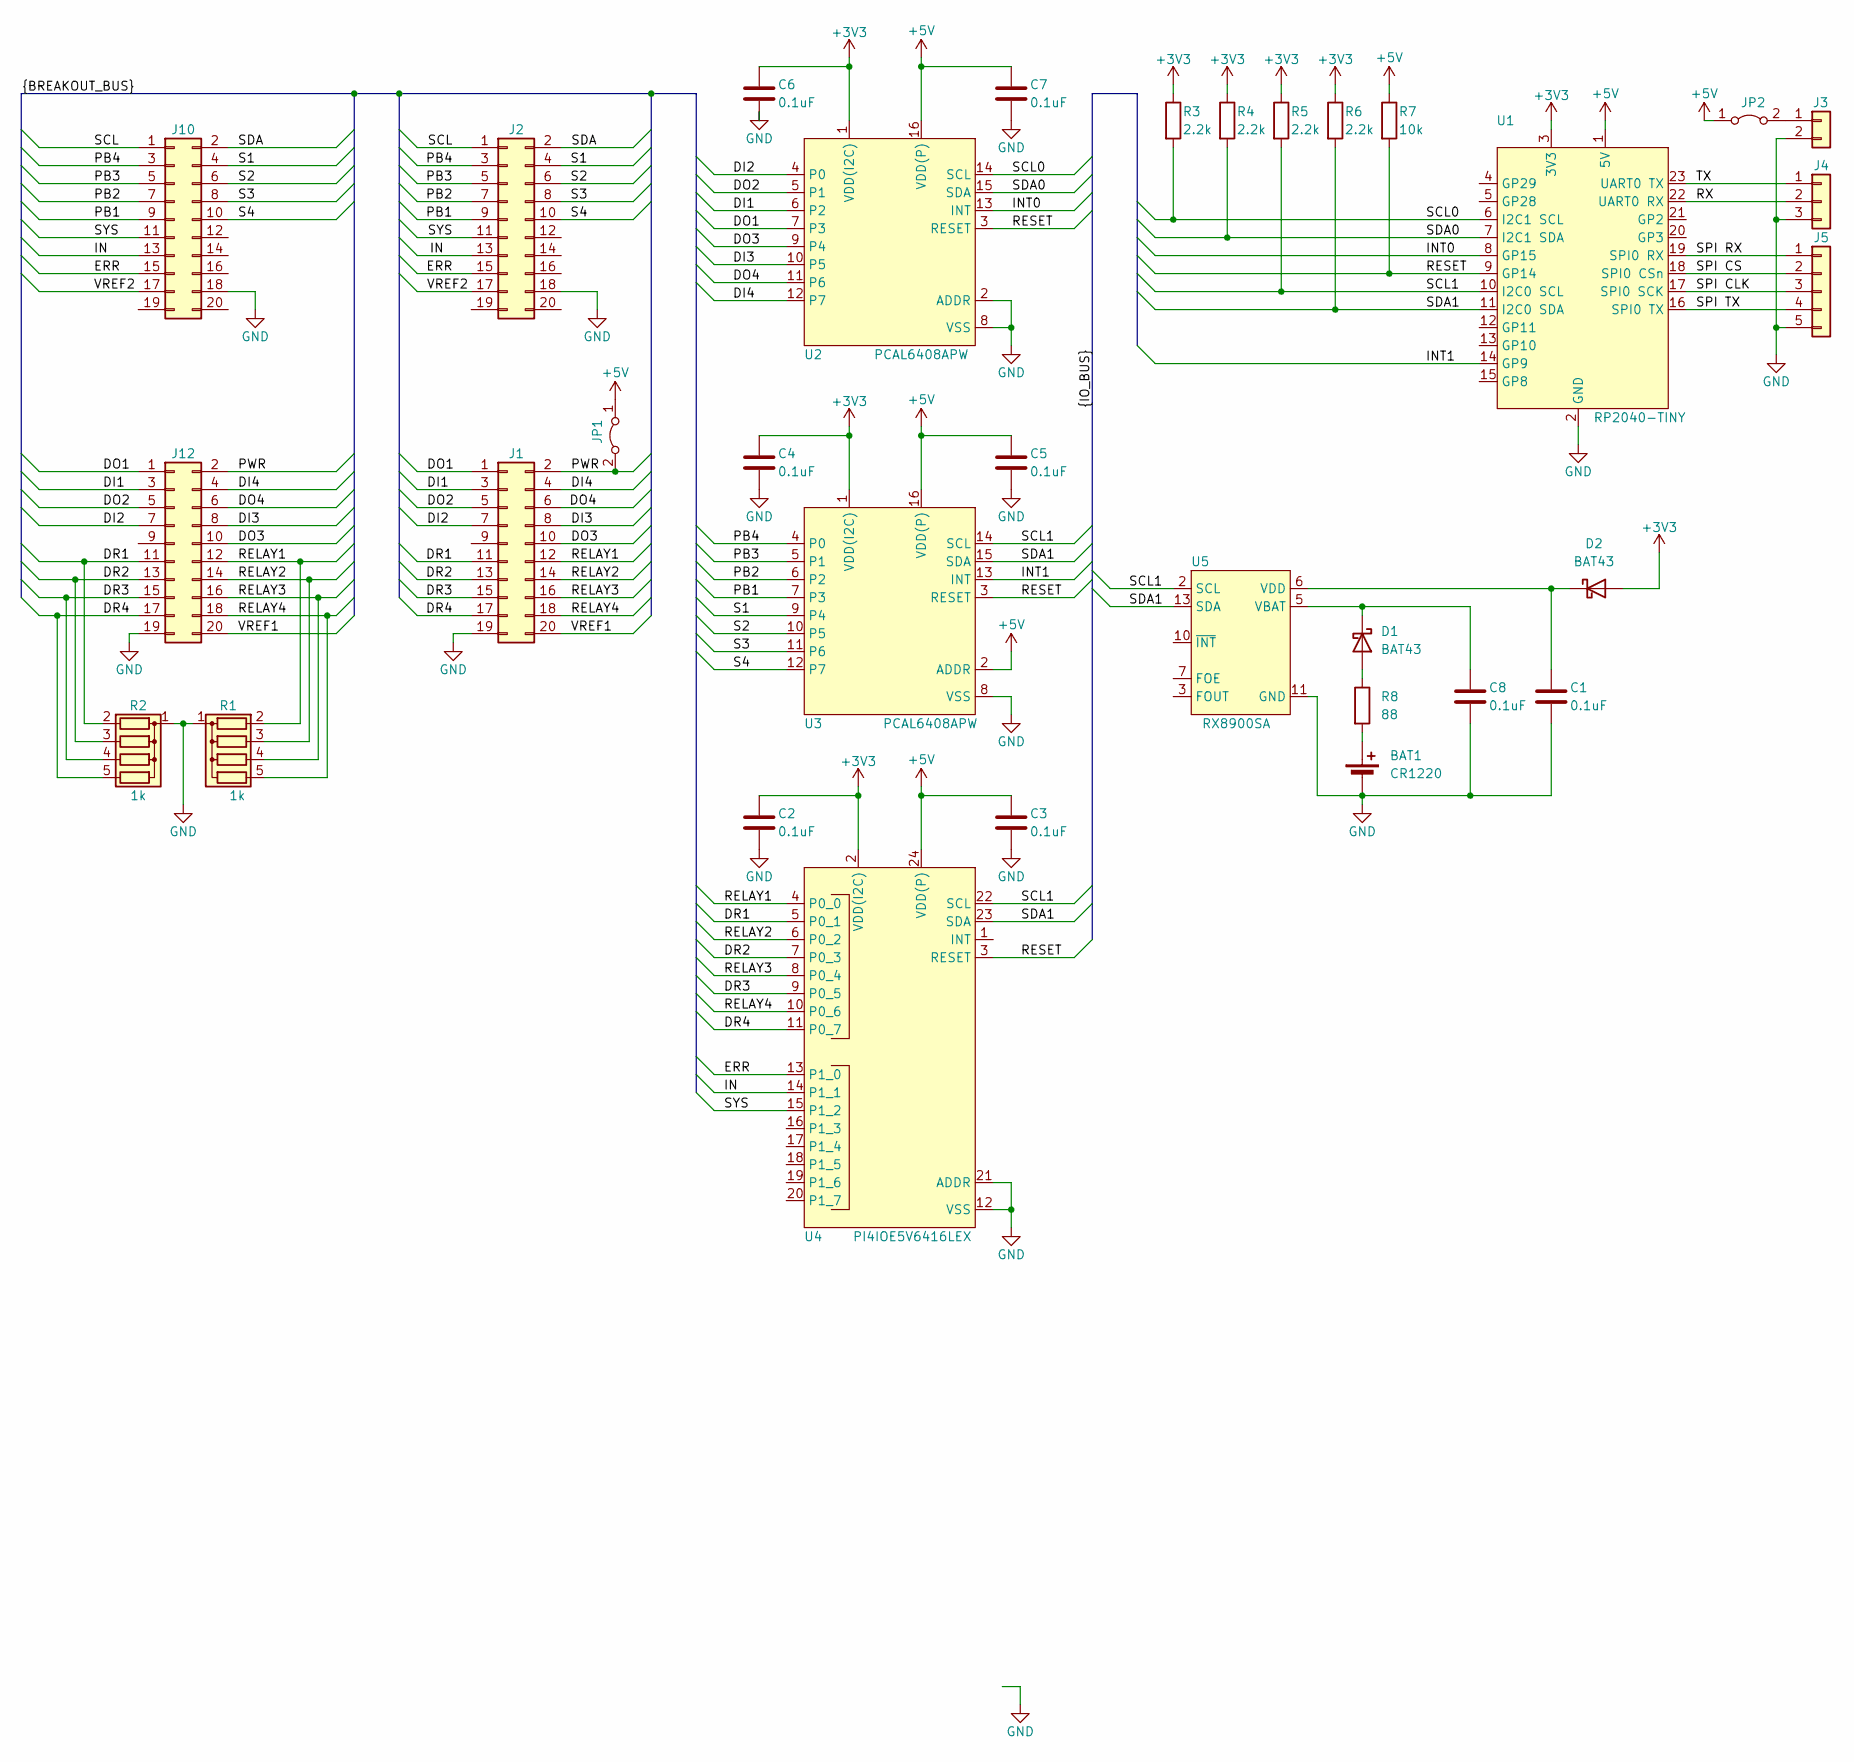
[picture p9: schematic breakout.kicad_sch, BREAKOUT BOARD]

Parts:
BAT1: CR1220; BatteryHolder_Keystone_3000_1x12mm
C1, C2, C3, C4, C5, C6, C7, C8: 0.1uF; C_0805_2012Metric_Pad1.18x1.45mm_HandSolder
D1, D2: BAT43; D_SOD-123
J1, J2: Conn_02x10_Odd_Even; PinHeader_2x10_P2.54mm_Vertical
J3: Conn_01x02; Molex_SPOX_5267-02A_1x02_P2.50mm_Vertical
J4: Conn_01x03_Pin; Molex_SPOX_5267-03A_1x03_P2.50mm_Vertical
J5: Conn_01x05_Pin; Molex_SPOX_5267-05A_1x05_P2.50mm_Vertical
J10, J12: Conn_02x10_Odd_Even; PinSocket_2x10_P2.00mm_Vertical
JP1, JP2: Jumper_2_Bridged; PinHeader_1x02_P2.54mm_Vertical
R1, R2: 1k; R_Array_SIP5
R3, R4, R5, R6: 2.2k; R_Axial_DIN0207_L6.3mm_D2.5mm_P10.16mm_Horizontal
R7: 10k; R_Axial_DIN0207_L6.3mm_D2.5mm_P10.16mm_Horizontal
R8: 88; R_1206_3216Metric_Pad1.30x1.75mm_HandSolder
U1: RP2040-TINY
U2, U3: PCAL6408APW; TSSOP-16_4.4x5mm_P0.65mm
U4: PI4IOE5V6416LEX; TSSOP-24_4.4x7.8mm_P0.65mm
U5: RX8900SA

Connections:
+3V3: C2.1, C4.1, C6.1, D2.2 (A), R3.1, R4.1, R5.1, R6.1, U1.3 (3V3), U2.1 (VDD(I2C)), U3.1 (VDD(I2C)), U4.2 (VDD(I2C))
+5V: C3.1, C5.1, C7.1, JP1.1 (A), JP2.1 (A), R7.1, U1.1 (5V), U2.16 (VDD(P)), U3.2 (ADDR), U3.16 (VDD(P)), U4.24 (VDD(P))
/DI1: J1.3, J12.3, U2.6 (P2)
/DI2: J1.7, J12.7, U2.4 (P0)
/DI3: J1.8, J12.8, U2.10 (P5)
/DI4: J1.4, J12.4, U2.12 (P7)
/DO1: J1.1, J12.1, U2.7 (P3)
/DO2: J1.5, J12.5, U2.5 (P1)
/DO3: J1.10, J12.10, U2.9 (P4)
/DO4: J1.6, J12.6, U2.11 (P6)
/DR1: J1.11, J12.11, R2.2 (R1), U4.5 (P0_1)
/DR2: J1.13, J12.13, R2.3 (R2), U4.7 (P0_3)
/DR3: J1.15, J12.15, R2.4 (R3), U4.9 (P0_5)
/DR4: J1.17, J12.17, R2.5 (R4), U4.11 (P0_7)
/ERR: J2.15, J10.15, U4.13 (P1_0)
/IN: J2.13, J10.13, U4.14 (P1_1)
/INT0: U1.8 (GP15), U2.13 (INT)
/INT1: U1.14 (GP9), U3.13 (INT)
/PB1: J2.9, J10.9, U3.7 (P3)
/PB2: J2.7, J10.7, U3.6 (P2)
/PB3: J2.5, J10.5, U3.5 (P1)
/PB4: J2.3, J10.3, U3.4 (P0)
/PWR: J1.2, J12.2, JP1.2 (B)
/RELAY1: J1.12, J12.12, R1.2 (R1), U4.4 (P0_0)
/RELAY2: J1.14, J12.14, R1.3 (R2), U4.6 (P0_2)
/RELAY3: J1.16, J12.16, R1.4 (R3), U4.8 (P0_4)
/RELAY4: J1.18, J12.18, R1.5 (R4), U4.10 (P0_6)
/RESET: R7.2, U1.9 (GP14), U2.3 (RESET), U3.3 (RESET), U4.3 (RESET)
/RX: J4.2, U1.22 (UART0 RX)
/S1: J2.4, J10.4, U3.9 (P4)
/S2: J2.6, J10.6, U3.10 (P5)
/S3: J2.8, J10.8, U3.11 (P6)
/S4: J2.10, J10.10, U3.12 (P7)
/SCL: J2.1, J10.1
/SCL0: R3.2, U1.6 (I2C1 SCL), U2.14 (SCL)
/SCL1: R5.2, U1.10 (I2C0 SCL), U3.14 (SCL), U4.22 (SCL), U5.2 (SCL)
/SDA: J2.2, J10.2
/SDA0: R4.2, U1.7 (I2C1 SDA), U2.15 (SDA)
/SDA1: R6.2, U1.11 (I2C0 SDA), U3.15 (SDA), U4.23 (SDA), U5.13 (SDA)
/SPI CLK: J5.3, U1.17 (SPI0 SCK)
/SPI CS: J5.2, U1.18 (SPI0 CSn)
/SPI RX: J5.1, U1.19 (SPI0 RX)
/SPI TX: J5.4, U1.16 (SPI0 TX)
/SYS: J2.11, J10.11, U4.15 (P1_2)
/TX: J4.1, U1.23 (UART0 TX)
/VREF1: J1.20, J12.20
/VREF2: J2.17, J10.17
GND: BAT1.2 (-), C1.2, C2.2, C3.2, C4.2, C5.2, C6.2, C7.2, C8.2, J1.19, J2.18, J3.2, J4.3, J5.5, J10.18, J12.19, R1.1 (common), R2.1 (common), U1.2 (GND), U2.2 (ADDR), U2.8 (VSS), U3.8 (VSS), U4.12 (VSS), U4.21 (ADDR), U5.11 (GND)
unnamed: BAT1.1 (+), R8.2
unnamed: D1.2 (A), R8.1
unnamed: C8.1, D1.1 (K), U5.5 (VBAT)
unnamed: C1.1, D2.1 (K), U5.6 (VDD)
unnamed: J3.1, JP2.2 (B)

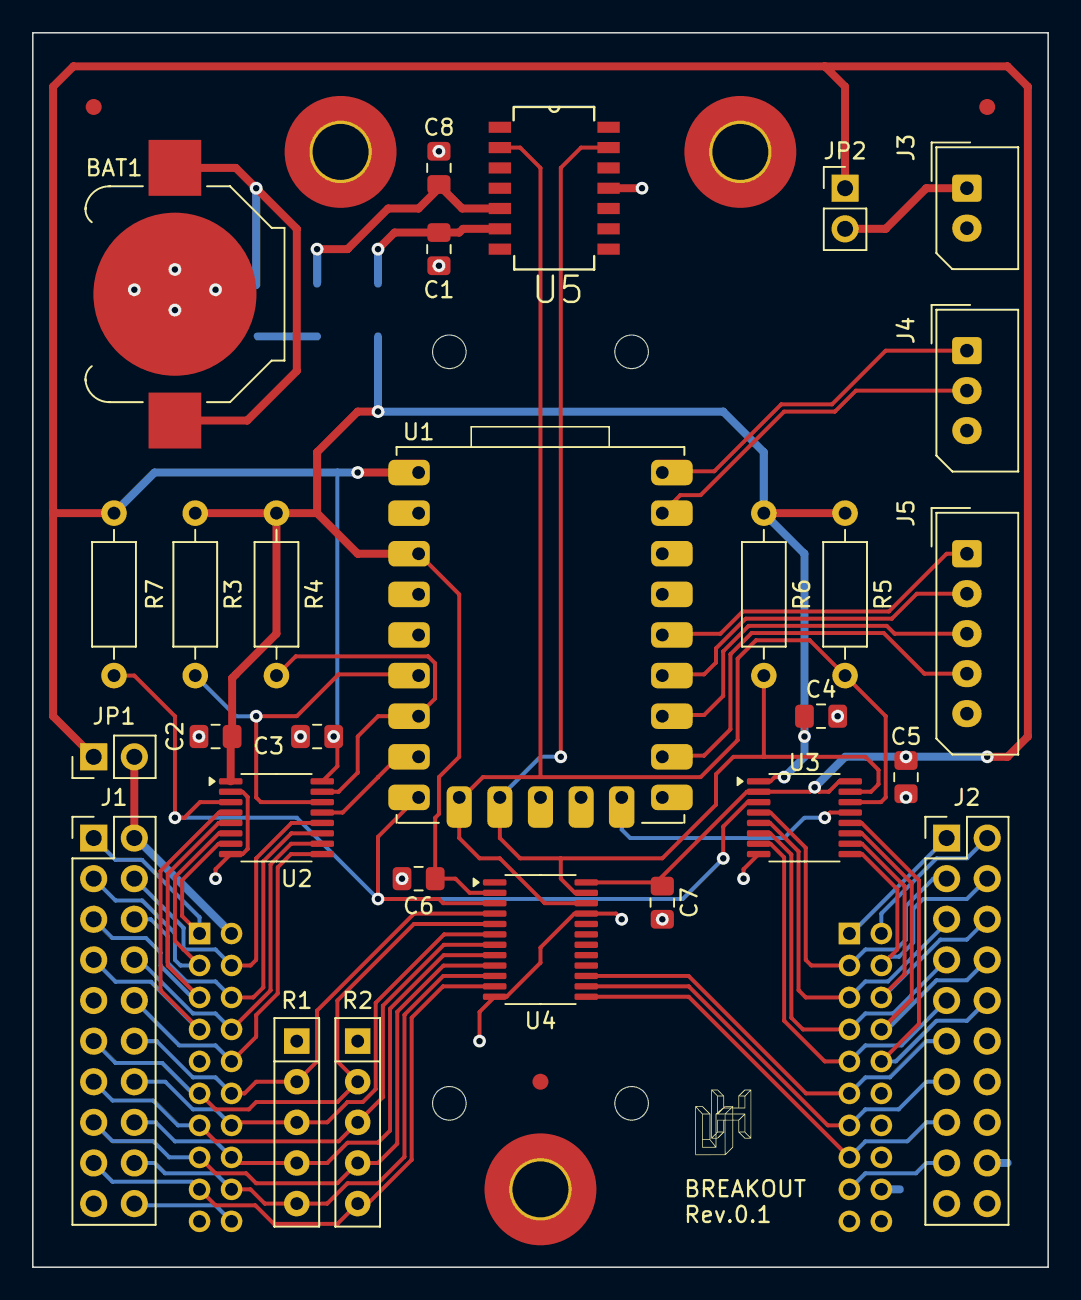
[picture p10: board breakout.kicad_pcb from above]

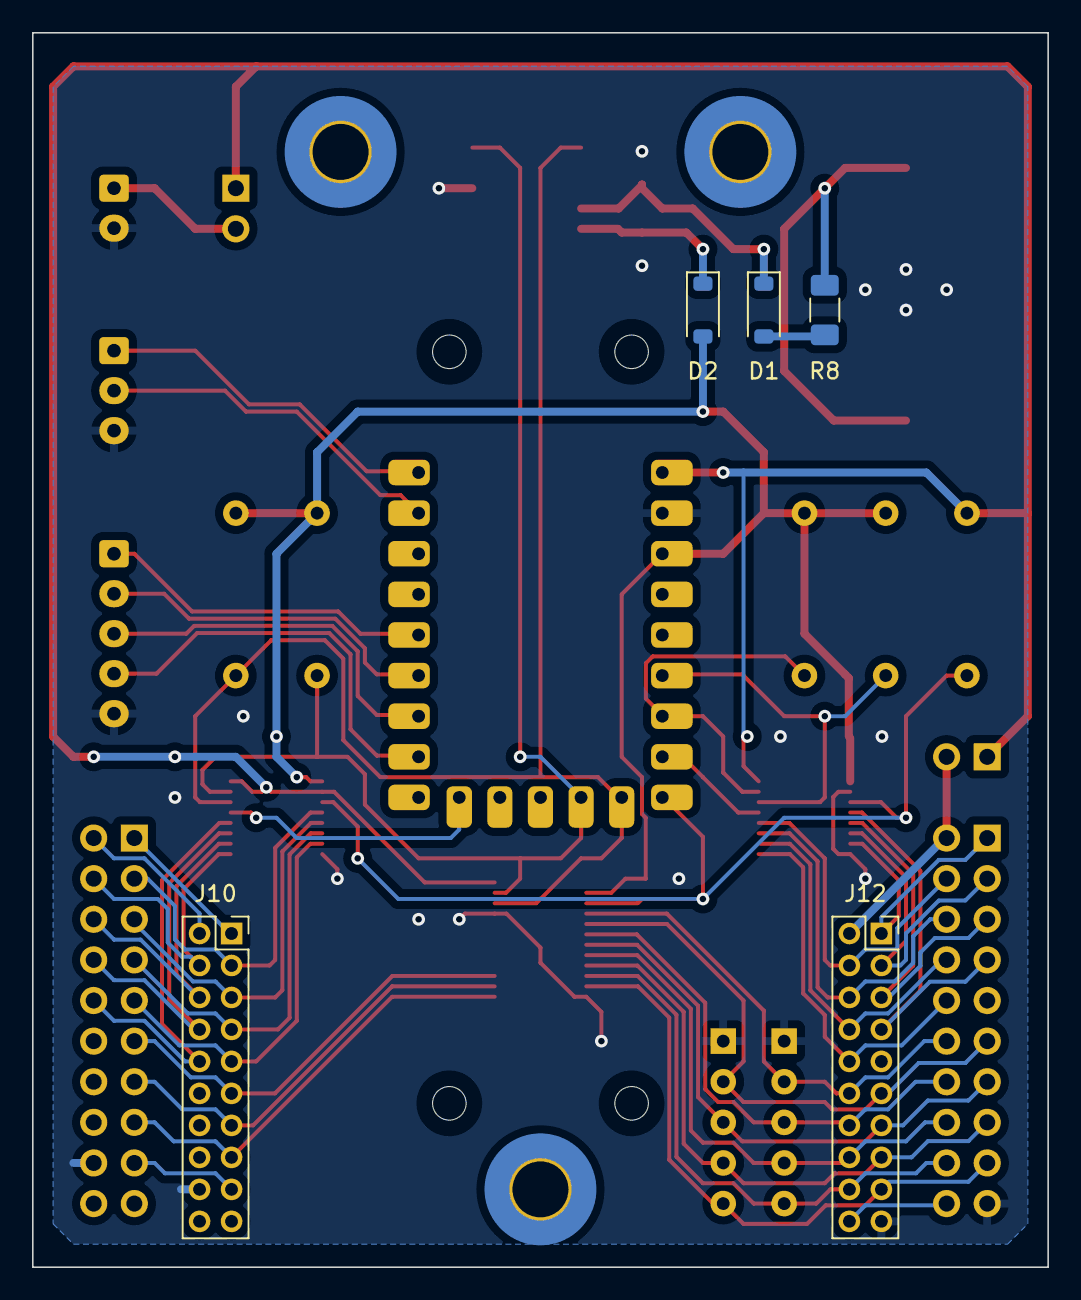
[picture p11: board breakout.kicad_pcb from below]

Board: 2 copper layers, 63.5 x 77.2 mm, 40 parts (5 on the bottom side), 53 nets.

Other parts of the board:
H1, H2, H3, H4: MountingHole_2.1mm
M1, M2, M2#2: MountingHole_3.5mm_Pad_TopBottom

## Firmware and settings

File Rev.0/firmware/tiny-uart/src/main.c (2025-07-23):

#include <stdio.h>
#include <stdlib.h>
#include <string.h>

#include <pico/binary_info.h>
#include <pico/multicore.h>
#include <pico/stdlib.h>

#include <hardware/watchdog.h>

#include <I2C0.h>
#include <I2C1.h>
#include <IOX.h>
#include <RTC.h>
#include <SSMP.h>
#include <breakout.h>
#include <log.h>
#include <mempool.h>
#include <sys.h>

#define LOGTAG "SYS"
#define _VERSION "v0.0"
#define _I2C0SDA 12
#define _I2C0SCL 13
#define _I2C1SDA 26
#define _I2C1SCL 27

queue_t queue;

const uint32_t WATCHDOG_TIMEOUT = 5000; // ms

int main() {
    bi_decl(bi_program_description("uhppoted-breakout"));
    bi_decl(bi_program_version_string(_VERSION));
    bi_decl(bi_2pins_with_func(_I2C0SDA, _I2C0SCL, GPIO_FUNC_I2C));
    bi_decl(bi_2pins_with_func(_I2C1SDA, _I2C1SCL, GPIO_FUNC_I2C));

    stdio_init_all();

    queue_init(&queue, sizeof(uint32_t), 64);
    alarm_pool_init_default();

    if (!mempool_init()) {
        warnf("SYS", "*** ERROR INITIALISING MEMPOOL");
        return -1;
    }

    // ... initialise system
    if (!sys_init()) {
        warnf("SYS", "*** ERROR INITIALISING SYSTEM");
        return -1;
    }

    syserr_set(ERR_RESTART, LOGTAG, "power-on");

    if (watchdog_caused_reboot()) {
        syserr_set(ERR_WATCHDOG, LOGTAG, "watchdog reboot");
    }

    if (strcmp(WATCHDOG, "disabled") != 0) {
        watchdog_enable(WATCHDOG_TIMEOUT, true);
    }

    // ... initialise FIFO, timers and I2C
    I2C0_init();
    I2C1_init();

    multicore_launch_core1(I2C0_run);

    // ... initialise RTC, IO expanders and serial port
    RTC_init();
    IOX_init();
    SSMP_init();

    sleep_ms(2500); // FIXME remove - delay to let USB initialise

    // ... good to go, start RTC, IO expanders and serial port
    RTC_start();
    IOX_start();
    SSMP_start();

    // ... POR events
    push((message){
        .message = MSG_EVENT,
        .tag = MESSAGE_EVENT,
        .event = EVENT_SYS_START,
    });

    if (watchdog_caused_reboot()) {
        push((message){
            .message = MSG_EVENT,
            .tag = MESSAGE_EVENT,
            .event = EVENT_SYS_RESET,
        });
    }

    // ... run loop
    while (true) {
        uint32_t v;

        queue_remove_blocking(&queue, &v);
        dispatch(v);
    }

    return 0;
}

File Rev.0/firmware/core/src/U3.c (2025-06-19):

#include <stdio.h>

#include <pico/stdlib.h>

#include <I2C0.h>
#include <PCAL6408A.h>
#include <U3.h>
#include <breakout.h>
#include <log.h>

#define LOGTAG "U3"

typedef struct IIR {
    float x₁;
    float y₁;
} IIR;

typedef struct LPF {
    float a₀;
    float a₁;
    float b₀;
    float b₁;
} LPF;

struct {
    struct {
        uint8_t state;
        IIR lpf[8];
    } inputs;

    struct {
        uint8_t state;
        IIR lpf[8];
    } stable;

    repeating_timer_t timer;
} U3x = {
    .inputs = {
        .state = 0x00,
        .lpf = {
            {.x₁ = 0.0, .y₁ = 0.0},
            {.x₁ = 0.0, .y₁ = 0.0},
            {.x₁ = 0.0, .y₁ = 0.0},
            {.x₁ = 0.0, .y₁ = 0.0},
            {.x₁ = 0.0, .y₁ = 0.0},
            {.x₁ = 0.0, .y₁ = 0.0},
            {.x₁ = 0.0, .y₁ = 0.0},
            {.x₁ = 0.0, .y₁ = 0.0},
        },
    },

    .stable = {
        .state = 0x00,
        .lpf = {
            {.x₁ = 0.0, .y₁ = 0.0},
            {.x₁ = 0.0, .y₁ = 0.0},
            {.x₁ = 0.0, .y₁ = 0.0},
            {.x₁ = 0.0, .y₁ = 0.0},
            {.x₁ = 0.0, .y₁ = 0.0},
            {.x₁ = 0.0, .y₁ = 0.0},
            {.x₁ = 0.0, .y₁ = 0.0},
            {.x₁ = 0.0, .y₁ = 0.0},
        },
    },
};

const uint8_t S1 = 0x10;
const uint8_t S2 = 0x20;
const uint8_t S3 = 0x40;
const uint8_t S4 = 0x80;

const uint8_t PB1 = 0x08;
const uint8_t PB2 = 0x04;
const uint8_t PB3 = 0x02;
const uint8_t PB4 = 0x01;

const uint8_t U3_MASKS[] = {S1, S2, S3, S4, PB1, PB2, PB3, PB4};
const uint8_t U3_DOORS[] = {0x00, 0x01, 0x02, 0x04, 0x08};
const uint8_t U3_BUTTONS[] = {0x00, 0x10, 0x20, 0x40, 0x80};
const int32_t U3_TICK = 1; // ms

const PULLUP U3_PULLUPS[8] = {
    PULLUP_UP, // PB4
    PULLUP_UP, // PB3
    PULLUP_UP, // PB2
    PULLUP_UP, // PB1

    PULLUP_UP, // S1
    PULLUP_UP, // S2
    PULLUP_UP, // S3
    PULLUP_UP, // S4
};

// 25Hz 1 pole Butterworth LPF (approx. 15ms debounce delay) for inputs
const struct LPF LPF₁ = {
    .a₀ = 1.0,
    .a₁ = -0.85408069,
    .b₀ = 0.07295966,
    .b₁ = 0.07295966,
};

// 0.1Hz 1 pole Butterworth LPF for input stability monitor
const struct LPF LPF₂ = {
    .a₀ = 1.0,
    .a₁ = -0.99937188,
    .b₀ = 0.00031406,
    .b₁ = 0.00031406,
};

// 5Hz 1 pole Butterworth LPF for input stability monitor
const struct LPF LPF₃ = {
    .a₀ = 1.0,
    .a₁ = -0.96906742,
    .b₀ = 0.01546629,
    .b₁ = 0.01546629,
};

bool U3_on_update(repeating_timer_t *rt);
void U3_read(void *data);
float lpf₁(IIR *iir, float in);
float lpf₂(IIR *iir, float in);

void U3_init() {
    infof(LOGTAG, "init");

    // ... configure PCAL6408A
    int err;

    if ((err = PCAL6408A_init(U3)) != ERR_OK) {
        warnf(LOGTAG, "error initialising PCAL6408A (%d)", err);
    }

    if ((err = PCAL6408A_set_configuration(U3, 0xff)) != ERR_OK) {
        warnf(LOGTAG, "error configuring PCAL6408A (%d)", err);
    }

    if ((err = PCAL6408A_set_polarity(U3, PB1 | PB2 | PB3 | PB4)) != ERR_OK) {
        warnf(LOGTAG, "error setting PCAL6408A polarity (%d)", err);
    }

    if ((err = PCAL6408A_set_pullups(U3, U3_PULLUPS)) != ERR_OK) {
        warnf(LOGTAG, "error setting PCAL6408A pullups (%d)", err);
    }

    if ((err = PCAL6408A_set_latched(U3, 0x00)) != ERR_OK) {
        warnf(LOGTAG, "error setting PCAL6408A latches (%d)", err);
    }

    if ((err = PCAL6408A_set_interrupts(U3, 0xff)) != ERR_OK) {
        warnf(LOGTAG, "error disabling PCAL6408A interrupts (%d)", err);
    }

    uint8_t inputs;
    PCAL6408A_read(U3, &inputs); // clear any existing interrupts

    debugf(LOGTAG, "initial state %02x %08b", inputs, inputs);
    infof(LOGTAG, "initialised");
}

// Starts the 1kHz input sampling
void U3_start() {
    infof(LOGTAG, "start");

    add_repeating_timer_us(1000 * U3_TICK, U3_on_update, NULL, &U3x.timer);
}

bool U3_on_update(repeating_timer_t *rt) {
    closure task = {
        .f = U3_read,
        .data = &U3x,
    };

    I2C0_push(&task);

    return true;
}

/*
 * I2C0 task to update U3 state from PCAL6408A.
 */
void U3_read(void *data) {
    uint8_t inputs;
    int err;

    if ((err = PCAL6408A_read(U3, &inputs)) != ERR_OK) {
        syserr_set(ERR_U3, LOGTAG, "error reading PCAL6408A inputs (%d)", err);
    } else {
        message qmsg = {
            .message = MSG_U3,
            .tag = MESSAGE_UINT32,
            .u32 = inputs,
        };

        push(qmsg);
    }
}

/*
 * Updates the input LPF's.
 */
void U3_process(uint8_t data) {
    uint8_t inputs = U3x.inputs.state;
    uint8_t stable = U3x.stable.state;
    uint8_t mask = 0x01;

    for (int i = 0; i < 8; i++) {
        // ... input filter
        float u = (data & U3_MASKS[i]) != 0x00 ? 1.0 : 0.0;
        float v = lpf₁(&U3x.inputs.lpf[i], u);

        if (v > 0.9) {
            inputs |= mask;
        } else if (v < 0.1) {
            inputs &= ~mask;
        }

        // ... unstable input filter
        float p = ((v > 0.9) || (v < 0.1)) ? 1.0 : 0.0;
        float q = lpf₂(&U3x.stable.lpf[i], p);

        if (q > 0.9) {
            stable |= mask;
        } else if (q < 0.1) {
            stable &= ~mask;
        }

        mask <<= 1;
    }

    if (inputs != U3x.inputs.state) {
        uint8_t old = U3x.inputs.state;
        U3x.inputs.state = inputs;

        debugf(LOGTAG, "inputs   %08b (%08b)", U3x.inputs.state, U3x.stable.state);

        static const struct {
            uint8_t mask;
            EVENT open;
            EVENT closed;
        } events[] = {
            {0x01, EVENT_DOOR_1_OPEN, EVENT_DOOR_1_CLOSE},
            {0x02, EVENT_DOOR_2_OPEN, EVENT_DOOR_2_CLOSE},
            {0x04, EVENT_DOOR_3_OPEN, EVENT_DOOR_3_CLOSE},
            {0x08, EVENT_DOOR_4_OPEN, EVENT_DOOR_4_CLOSE},

            {0x10, EVENT_DOOR_1_RELEASED, EVENT_DOOR_1_PRESSED},
            {0x20, EVENT_DOOR_2_RELEASED, EVENT_DOOR_2_PRESSED},
            {0x40, EVENT_DOOR_3_RELEASED, EVENT_DOOR_3_PRESSED},
            {0x80, EVENT_DOOR_4_RELEASED, EVENT_DOOR_4_PRESSED},
        };

        // ... door open/close/pressed/released
        int N = sizeof(events) / sizeof(events[0]);

        for (int i = 0; i < N; i++) {
            uint8_t mask = events[i].mask;

            if (((U3x.inputs.state & mask) == 0x00) && ((old & mask) == mask)) {
                push((message){
                    .message = MSG_EVENT,
                    .tag = MESSAGE_EVENT,
                    .event = events[i].open,
                });
            }

            if (((U3x.inputs.state & mask) == mask) && ((old & mask) == 0x00)) {
                push((message){
                    .message = MSG_EVENT,
                    .tag = MESSAGE_EVENT,
                    .event = events[i].closed,
                });
            }
        }
    }

    if (stable != U3x.stable.state) {
        U3x.stable.state = stable;

        debugf(LOGTAG, "inputs   %08b (%08b)", U3x.inputs.state, U3x.stable.state);
    }
}
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

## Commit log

2024-05-08 Initial import
    [RX8900SA-body.stl, RX8900SA-dot.stl, RX8900SA-label.stl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]
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2024-05-10 Fixed typo in BOM
2024-05-14 Added Gerber files for JLOCB
2024-05-15 Updated REV.0 BOM and bringup checklist
2024-05-16 Reorganised to put all Rev.0 stuff in one folder
    [breakout.kicad_pcb, breakout.kicad_sch]
2024-05-18 Rev.0: Pico firmware initial import
2024-05-20 Rev.0: Pico firmware CLI skeleton
2024-05-20 Rev.0: corrected U1 to WaveShare RP2040-TINY
    [breakout.kicad_pcb, breakout.kicad_sch]
2024-05-22 PCAL6408APW: reset and I2C initialisation
    [hwconfig.c]
2024-05-22 PCAL6408APW: moved Pico I2C0 to GP8/9
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2024-05-27 Queued WIO from U2 interrupt handler
2024-05-29 U3 PCAL6408APW driver implementation
2024-05-29 Restructured I2C stuff to bundle bus+address
2024-05-30 U4 PI4IOE5V6416 driver implementation
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2024-06-04 Fixed RP2040-Tiny 3D model offset
    [breakout.kicad_pcb]
2024-06-05 Rev.0/firmware: porting Pico code to Tiny
2024-06-06 TINY: RTC and LEDs
2024-06-06 Rev.0: restructured Pico firmware for shared components
2024-06-09 Corrected U2 and U3 interrupt handling for level sensitive interrupts
    [I2C0.c, IOX.c, U2.c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]
2024-06-10 Reworked set date/time/datetime to use parameters from command
    [U2.c, cli.c]
2024-06-11 I2C0 work queue skeleton
2024-06-11 Reworked I2C0 queue to use a closure
    [I2C0.c, cli.c]
2024-06-13 Reworked RTC to cache RX8900SA date/time/dow
    [RTC.c, cli.c]
2024-06-13 Reworked syserror to take error description
    [I2C0.c, RTC.c, U2.c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]
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2024-06-14 Reworked RTC set date/time to use I2C0 task queue
    [RTC.c, main.c, sys.c]
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2024-06-15 Ditching SPI in favour of bidirectional serial commms
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2024-06-17 Modelling input RC filter
2024-06-18 Replaced U3 interrupt handler with 1kHz sampling
    [U2.c, U3.c, cli.c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]
2024-06-19 Fixed U3 IIR filter coefficients
    [U3.c, cli.c]
2024-06-19 Optimized U3 input IIR filter
2024-06-20 Restructured U4 to use I2C0 task scheduler
2024-06-20 U4 set relay delay
2024-06-20 U4 blink door LED
2024-06-24 Reworked relays to use clocked timers (for retriggering)
    [U4.c]
2024-06-25 Reworked U4 relays logic to lookup relay by ID
    [U4.c]
2024-06-25 Fixed startup initialisation sequence (queue was not initialised first)
    [U4.c, cli.c, main.c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]
2024-06-26 Reworked set/clear/blink LED as 'ticked' operations
    [U4.c]
2024-06-26 Reworked U4x struct to include SYS,IN and ERR LEDs
    [U4.c, cli.c]
2024-06-28 Reworked U4 to use clocked output write
    [U4.c, cli.c]
2024-06-28 Archiving 'as built' kicad files as 'kicad Rev 0.0'
    [breakout.kicad_pcb, breakout.kicad_sch]
2024-06-29 Rev 0.1 added backup battery Schottky diodes
    [breakout.kicad_pcb, breakout.kicad_sch]
2024-06-29 Rev 0.1: shuffled decoupling capacitors to correct side of Schottky diodes
    [breakout.kicad_pcb, breakout.kicad_sch]
2024-07-01 Rev 0.1: added RTC battery Schottky diodes
    [breakout.kicad_pcb, breakout.kicad_sch]
2024-07-01 kicad: Zero2W mounting holes footprint
2024-07-02 U4: inverted polarity of SYS, IN and ERR LEDs
    [breakout.kicad_pcb]
2024-07-02 Added (provisional) power consumption measurements to design notes
2024-07-05 U3: added 'stability' estimator to inputs
    [U3.c]
2024-07-06 U3: reworking stability estimator to estimate 'instability'
    [U3.c]
2024-07-08 U3: reworked input stablity estimator as an asymmetrical LPF
    [U3.c]
2024-07-16 Added compile time flags for I2C0 and I2C1 clock rates
2024-07-19 Added RX8900SA battery diodes and resistors to flip side of PCB
    [breakout.kicad_pcb, breakout.kicad_sch]
2024-07-19 Reworked CLI to use scrollable for system messages and command area for commands
    [cli.c]
2024-07-22 Removed unused I2C0/1 functions
2024-07-22 Reworked CLI help to display in panel at top/right
    [cli.c]
2024-07-24 Setting on-board RTC from RX8900SA
2024-07-24 Migrating to a managed printf queue
2024-07-24 Reworked RTC to use onboard RTC for get-date/time/dow
    [RTC.c, main.c]
2024-07-24 Added 64us delay for on-board RTC to stabilize after init(..)
    [RTC.c, main.c]
2024-07-25 Added guard around printf's
2024-07-25 Fixed CLI timeout bug
    [cli.c]
2024-07-26 Added guards to I2C0/1
2024-07-26 Disabled sys print/println in SSMP mode
2024-07-31 Reordered and reorganised system startup to avoid clearing already logged messages
    [cli.c, main.c, sys.c]
2024-08-01 logging: dropped block of 8 message on print queue full
2024-08-01 sys::_print to print all of message
2024-08-06 Replaced USB connected with TTY device status ping
    [cli.c, main.c, sys.c]
2024-08-07 Reworked USB/serial to use byte buffer rather than string to support binary protocols
    [cli.c, sys.c, uart.c]
2024-08-08 Set LED 'off' colour by SYS mode
2024-08-13 ssmp: RP2040 revert to MODE_UNKNOWN on idle timeout
    [main.c, sys.c]
2024-08-16 CLI: reworked terminal report parser to handle multiple messages in a buffer
    [cli.c]
2024-08-19 Fixed stdout flush logic in sys::print
    [cli.c, sys.c]
2024-08-21 ssmp: fixed BLE length decoding
    [cli.c]
2024-08-29 Fixed missing file in pico build
2024-09-03 bisync: replaced 'message' struct with slice
    [cli.c]
2024-09-04 ssmp: reset idle timer on set-mode:SSMP
    [sys.c]
2024-09-11 ssmp: replaced CRC-CCITT with CRC-DNP
    [cli.c]
2024-09-13 Removed USB CRLF hack from Pico build
2024-09-16 ssmp: removed USB CRLF translation from pico build
2024-09-17 on-device test: initial project skeleton
2024-09-18 ASN.1: fixed integer encoding
    [main.c]
2024-09-19 Fixed ASN.1 integer decoding
    [main.c]
2024-10-07 SSMP: adding board-id to MIB
2024-10-09 ssmp: added VERSION to pico variant
2024-11-12 Migrating SSMP off USB to UART0
2024-11-12 Updated Pico target with compile-time RELEASED
2024-11-13 Migrated SSMP GET to UART0
2024-11-13 Fixed Makefile build-all target for moved Go emulator
    [cli.c]
2024-11-14 Added UART uart, pins and IRQ to hwconfig
2024-11-15 Debugging SSMP interrupt handler weirdness
2024-11-19 *STILL* debugging the weird issue
    [U3.c, cli.c, sys.c]
2024-11-20 Replaced MSG_USB with in-USB logging
    [main.c, sys.c]
2024-11-21 Commonalising SSMP circular buffer for UART and USB
2024-11-21 Moved 'mode ping' to core/sys (for printf mutex)
2024-11-22 Reworked CLI to process 'in message' ESC characters
    [cli.c]
2024-11-22 Reworked USB and UART to use circular buffer
    [cli.c, sys.c, uart.c]
2024-11-23 Reworked SSMP and CLI to use buffer flush(..)
    [cli.c, uart.c]
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2024-11-23 Moved SSMP to UART1
2024-11-23 Added WATCHDOG to system errors and CMake build flags
    [main.c, sys.c]
2024-11-25 Replace seperate USB and UART CLI rx handlers with unified stdio implementation
    [cli.c, sys.c]
2024-11-25 (interim) splitting Rev.0 Go emulator into emulator+driver
2024-11-26 Restructuring Go emulator to use stub driver
2024-11-26 Replaced print queue with preallocated circular list
    [sys.c]
2024-11-26 Removed calloc+free in print/println/_push
2024-11-27 Replaced print/println in-call flush with queued MSG_LOG
    [main.c, sys.c]
2024-11-27 Removed superfluous 'println' implementation
2024-11-29 Implemented '...' log entry if print queue overflows
2024-11-29 emulator: RPC driver skeleton
2024-12-02 Identified SSMP echo RESET/BOOTSEL artifact (add pullups to UART pins)
    [hwconfig.c]
2024-12-04 Added mutex around print queue push/pop
2024-12-06 (debug) added mutex around LED and checked SSMP message against 'expected' message
2024-12-07 driver: SSMP simulator skeleton
2024-12-09 (debug) printing timer info to stdout
2024-12-11 emulator: set-listener API function
    [pyvenv.cfg]
2024-12-14 (debug) removed U4 again (glitch)
    [IOX.c]
2024-12-16 Fixed inverted 'memory error' flag in sys_healthcheck
    [sys.c]
2024-12-17 emulator: genericized driver 'get'
2024-12-17 (glitch) reinstated U4::tick relays
    [U4.c]
2024-12-18 (glitch) reinstated U4::tick outputs
    [U4.c]
2024-12-19 (glitch) reinstated U4::tick LEDs
    [U4.c, sys.c]
2025-01-02 Added notes re. malloc/free + interrupts
2025-01-06 breakout: reworking U4 to use mempool
    [U4.c, main.c]
2025-01-06 breakout: added 'trace' implementation from glitch branch
2025-01-08 emulator: implemented exponential backoff when reopening a listen socket
2025-01-08 breakout: reworked mempool to take size parameter in 'init'
    [U4.c]
2025-01-10 breakout: fixed allocs in ssmp_encode_get_response
    [U4.c]
2025-01-15 breakout: reworked U2 to use mempool
    [IOX.c, U2.c, U3.c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]
2025-01-16 emulator: added support for Unix domain sockets
2025-01-18 breakout: reworked RTC to use mempool
    [RTC.c]
2025-01-18 Restructured folders to consolidate all Zero2W stuff
    [pyvenv.cfg]
2025-01-22 breakout: U2 - fixed keycode (to use code length arg)
    [U2.c]
2025-02-03 breakout: configurable trace interval
2025-02-05 breakout: added 'trace XX' command to the CLI
2025-02-08 breakout: migrated U2,U3,UART and USB to use queue::push
2025-02-10 breakout: verified inputs, LEDs and relays still working after migrating to mempool
2025-02-13 breakout: reworked U4 healthcheck to only run every 1s irrespective of 'op ok'
    [U4.c]
2025-02-13 breakout: moved error handling to breakout.c
    [I2C0.c, RTC.c, U2.c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]
2025-02-19 breakout: updated to Pico SDK 2.1.1
2025-02-19 breakout: explicity set I2C GPIO slew rate and drive
2025-02-21 breakout: set drive levels for SYS, ERR and IN LEDs
2025-02-27 breakout: removed superfluous 'set-error' calls for I2C0::push
    [I2C0.c, RTC.c, U3.c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]
2025-03-05 breakout: tiny-usb implementation (partial/reboot)
    [sys.c]
2025-03-05 breakout: updated github workflow for tiny-uart
2025-03-07 breakout: added SSMP mode compile definition to tiny-uart
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2025-04-02 breakout: SSMP get-tamper-detect and get-fire-alarm
    [RX8900SA-body.stl, RX8900SA-dot.stl, RX8900SA-label.stl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]
2025-04-09 Reworked set-time to delay for 1ms and then return current RTC time
2025-04-09 Implement SSMP readonly, not-writable, wrong-type and no-access errors
    [RTC.c]
2025-04-15 breakout: replaced on-chip RTC with basic software RTC
    cf.:
    - https://forums.raspberrypi.com/viewtopic.php?t=325598
    - https://forums.raspberrypi.com/viewtopic.php?t=377876
    - https://forums.raspberrypi.com/viewtopic.php?t=348730
    [RTC.c, cli.c]
2025-04-23 breakout: reinstated error message for syserror
    [breakout.c]
2025-04-24 breakout: included all errors in CLI 'state' command
    [cli.c]
2025-04-28 breakout: reworked set_error to only log queue/memory/etc errors once
    [breakout.c, cli.c]
2025-04-29 breakout: reworked set_error to log every N errors
    [breakout.c]
2025-04-30 breakout: reworked syserror with loggable interval
    [breakout.c, sys.c]
2025-05-01 breakout: added 'clear errors' to CLI
    [breakout.c, cli.c]
2025-05-01 breakout: added get/set for individual system errors to MIB
    [I2C0.c, RTC.c, breakout.c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]
2025-05-07 breakout: reworking RTC to use microsecond timer sync'ed to RX8900SA
    [RTC.c]
2025-05-08 breakout: switched to internal µs timer for RTC
2025-05-12 breakout: (interim fix) set RTC µs on write to reduce delta
    [RTC.c]
2025-05-14 breakout: reworked RTC to clear 'ready' after write
    [RTC.c]
2025-05-22 breakout: added anti-windup to RTC PID
2025-05-26 breakout: reset RTC and set syserror flag if synchronisation error is greater than 5s
    [RTC.c]
2025-05-26 breakout: wrapped up hardware timer RTC
2025-06-05 breakout: reworked USB/UART write to return true/false
    [uart1.c]
2025-06-12 breakout: added event traps for door buttons pressed/released
2025-06-16 breakout: fixed watchdog enable
    [breakout.c, cli.c, main.c]
2025-06-25 eventd: added modernc sqlite3 driver (CGO cross-compilation complications)
2025-08-07 breakout: fixed typo in card swipe event handling
    [sys.c]
2025-08-12 get-status: fetching door-open/button state from UT0311::state
2025-08-20 dbd: unified mattn:sqlite3 and modernc:sqlite driver implementations
2025-08-25 ut0311: moved door unlock relays to 'state'
2025-09-10 breakout: reworked settings::save to write to flash iff actually changed
    [cli.c]
2025-09-24 ut0311: card + PIN (in progress)
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2025-10-01 ut0311: send 'denied' event on new card swipe while previous swipe is pending PIN
2025-10-06 ut0311: (in progress) resetting timer on keypress
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2025-10-09 breakout: fixed shift logic in PCAL6416A reads
    [cli.c]
2025-10-09 breakout: reset keypad on card swipe
    [U2.c, hwconfig.c]
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2025-10-29 breakout: fixed missing usb1_write in tiny-uart
    [sys.c]
